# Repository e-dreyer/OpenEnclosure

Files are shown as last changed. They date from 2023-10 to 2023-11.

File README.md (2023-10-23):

# OpenEnclosure

## Important links and the structure of this guide

- For the initial setup, construction and only configuring the `WiFi` of the printer and enclosure, please follow this [guide](https://github.com/e-dreyer/OpenEnclosure/tree/main/intial_setup)
- For the original manual of the CR6-SE, please refer to this [PDF](https://github.com/e-dreyer/OpenEnclosure/tree/main/manual)
- For all of the slicer configs and profiles please refer to the [Slicer Profiles](https://github.com/e-dreyer/OpenEnclosure/tree/main/slicer_profiles) section.

## System Architecture

This is my implementation for my 3D printing enclosure. The enclosure runs the following software:

- **Klipper**: The `firmware` for the printer. [Klipper](https://www.klipper3d.org/) is installed on both the printer and the `Raspberry Pi`
- **Mainsail**: The front-end for `Klipper`, which allows for a simple interface with the printer. You can find the official documentation [here](https://docs.mainsail.xyz/)
- **Moonraker**: An API server used by both `Klipper` and `Mainsail` to communicate with each other. You can find the official documentation [here](https://moonraker.readthedocs.io/)
- **ESP Home**: The `firmware` for the `ESP32` which controls the enclosure heating and lights. You can find the official documentation [here](https://esphome.io/)
- **Mosquito**: A `MQTT Broker` used to implement communication between the `ESP32`, printer and `Raspberry Pi`. Here you can find [easy installation instructions](https://randomnerdtutorials.com/how-to-install-mosquitto-broker-on-raspberry-pi/) but it will be explained in the following sections.

## Fresh Install

This section is only relevant if the user wishes to do a complete fresh installation of the entire system. If you wish to only configure the `WiFi` settings, please refer to this [guide](https://github.com/e-dreyer/OpenEnclosure/tree/main/intial_setup).

This could be necessary if they user bricked the system in some way, which is not easily possible, they wish to reproduce the original system or wish to replicate it and create a new system. It is advised that a user reads the entire installation process for better understanding. This process might appear intimidating, but is actually quite simple and can easily be completed in about an hour of simply typing `Linux` terminal commands.

An important thing to note is, when completing a fresh install, the `Raspberry Pi` will have no network connection initially. Thus, it is required to connect the `Raspberry Pi` to an external monitor with a keyboard and a `wireless dongle`. The fresh operating system `MainsailOS` will then be installed and the initial setup will be completed. Once the network configuration has been completed, the user can disconnect the `Raspberry Pi` from the external monitor and use `SSH` for further configuration.

Only completed the following section if you are running a fresh install. Otherwise skip directly to the network configuration if you wish to connect the system to a new network and the software has already been installed.

### Klipper, Mainsail and Moonraker

In this section we will be installing `MainsailOS`. `MainsailOS` is a `Linux` based operating system, which is pre-configured to run `Klipper`, `Mainsail` and `Moonraker`. This simplifies the installation process and the user is only required to flash a new operating system to the `Raspberry Pi` for the installation of `Klipper`.

We will start by downloading and installing `rpi-imager` on a secondary computer to create an operating system image for the `Raspberry Pi` `SD card`. You can easily download it from [here](https://www.raspberrypi.com/software/) or use the following command on a `Linux` system

```bash
sudo apt install rpi-imager
```

1. Open `rpi-imager` and click `Other specific-purpose OS > 3D Printing > Mainsail OS` and choose the `32-bit` version.
2. Insert the `SD card` of the `Raspberry Pi` into the computer and select it as the storage device for `rpi-imager`.
3. Click the `gear-icon` in the bottom right corner of `rpi-imager`
4. Set `hostname` as `mainsail.local`.
5. Enable `SSH` with `Use password authentication`, default `username = pi` and `password = root`
6. Skip `Configure Wireless LAN` as this does not always work and will be configured in the next step in order to be more reliable and work correctly
7. Click `Save`
8. Click `Write`. If prompted to format the `SD card` click `yes`.
9. Wait for the installation to complete. This might take a few minutes depending on internet speed and the write speed of the `SD card`

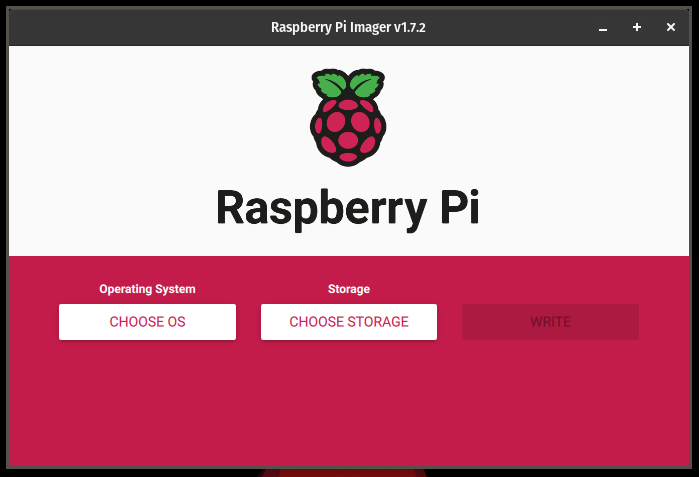
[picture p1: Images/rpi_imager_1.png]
Home screen of RPI imager


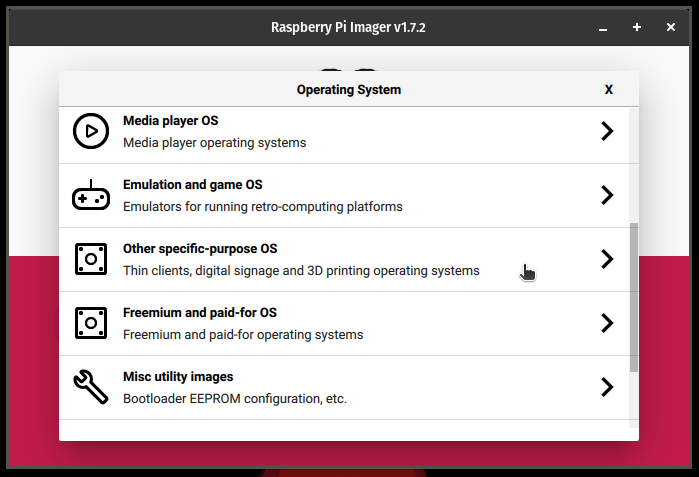
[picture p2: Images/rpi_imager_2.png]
Selecting the image category


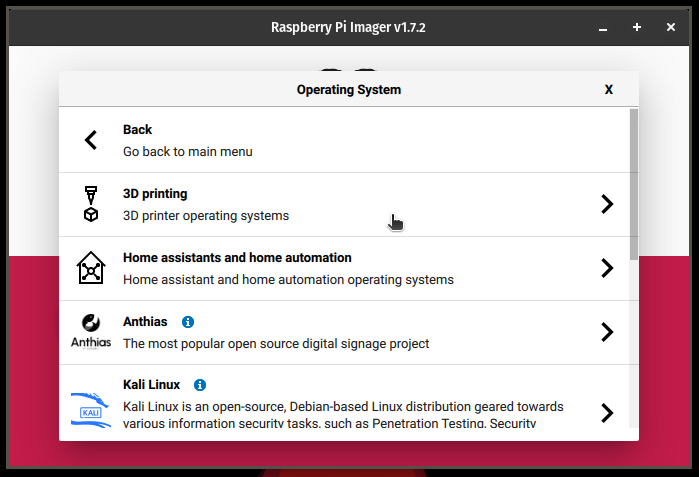
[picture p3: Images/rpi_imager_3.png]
Selecting 3D printing menu


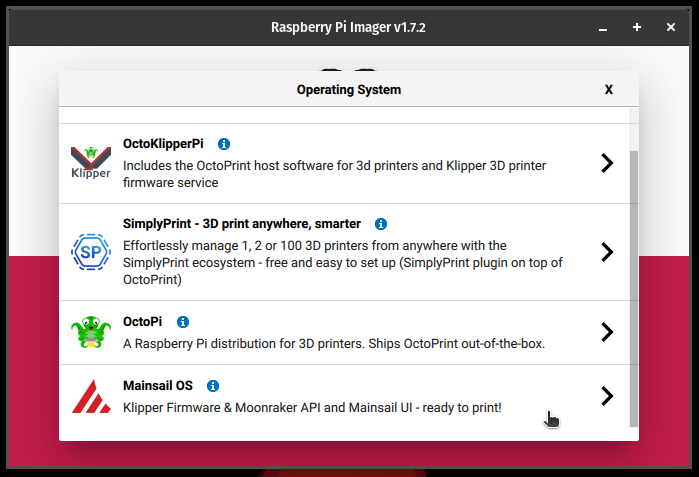
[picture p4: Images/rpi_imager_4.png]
Selecting MainsailOS


Remove the `SD card` from the computer and insert it into the `Raspberry Pi`. Connect the `Raspberry Pi` to an HDMI monitor and a keyboard and finally connect the power. Wait for the `Raspberry Pi` to boot. Ensure that your `WiFi dongle` is plugged into the `Raspberry Pi`.

### Setting up WiFi, SSH and static IP

==This should be completed for the initial setup in order to connect the Raspberry Pi to your network as well as after an initial fresh install of Klipper and MainsailOS as explained in the previous section==

#### Rasp-Config

On the first boot, the screen may flash a test image, simulating a rainbow pattern and present a scrolling terminal of text showing checks and other information. Wait for the this screen to stop scrolling and wait for a prompt asking for your username:

```bash
raspberrypi login: 
```

Enter `pi`. A next prompt asking for your password will be shown. Important, while typing in your password, no text will be shown in the terminal. Enter `root`:

```bash
Password: 
```

Next we need to configure the `Raspberry Pi`. Run the following command in the terminal. You may be prompted for your password, enter the password as configured previously or the default password `root`

```bash
sudo raspi-config
```

Use the arrow keys to select `1 System Options`, select `S1 Wireless LAN` enter the `SSID` of your `WiFi network`. The `SSID` is the name of your network, such as the name shown on a phone or computer when connecting to the network. Be sure to enter it perfectly as it is case-sensitive.

After entering your `SSID` press `enter` and you will be prompted for your `password`. This is the password for your `WiFi network`. Press enter once complete.

You'll be returned to the home screen. Select `1 System Options` again and select `Hostname`. Enter your own desired unique hostname. For this guide the hostname `mainsail` was chosen. Press enter once complete.

On the home screen again, select `3 Interface Options` and select `I2 SSH`, follow the guide to enable `SSH`. Repeat this for the same menu `3 Interface Options` to enable `I4 SPI`, `I5 I2C`, `I6 Serial Port`, `I7 1-Wire` and `I8 Remote GPIO`. 

- `SSH` allows you to login to your `Raspberry Pi` over a remote terminal connection
- `SPI`, `I2C` and `1-Wire` are all communication protocols which can be used to communicate with external sensors and modules. Not all of them are necessarily used with the current implementation, but enabling them might allow for easier setup in the future.
- `Serial Port` allows for serial communication over USB
- `Remote GPIO` allows for controlling the `GPIO` pins remotely. This is often used by some `Android` apps and other applications and enabling it now would also simplify future configurations.

Back on the home screen of `raspi-config`, press the `right-arrow key` to move the cursor to the `Finish` button in the bottom right corner. Press `enter`. If prompted to `reboot`, select `yes` and press `enter`. The `Raspberry Pi` will restart. Wait for this to finish and login with your `username` and `password` again once the reboot has been completed.

#### WiFi

Although the `WiFi` settings have been enabled and you provided your `SSID` and `password` in the previous section, this does not always work, depending on your `Wifi dongle` and network. Thus the following configuration should be completed:

Enter the following commands line by line separately in the terminal, pressing `enter` after every line. Be sure to replace `ssid` with your `WiFi network name` and `password` with your `password`. They should be enclosed by the single quotes.

```bash
sudo rfkill unblock wifi
sudo sh -c "wpa_passphrase 'ssid' 'password' >> /etc/wpa_supplicant/wpa_supplicant.conf"
sudo wpa_cli -i wlan0 reconfigure
```

`Reboot` the `Raspberry Pi` again by typing `reboot` into the terminal. Wait for the `Raspberry Pi` to reboot and login again.

Once the system is booted, enter the command `ifconfig` and you'll be presented by an output such as the following:

```bash
pi@mainsail:~ $ ifconfig
eth0: flags=4099<UP,BROADCAST,MULTICAST>  mtu 1500
        ether b8:27:eb:3c:98:b5  txqueuelen 1000  (Ethernet)
        RX packets 0  bytes 0 (0.0 B)
        RX errors 0  dropped 0  overruns 0  frame 0
        TX packets 0  bytes 0 (0.0 B)
        TX errors 0  dropped 0 overruns 0  carrier 0  collisions 0

lo: flags=73<UP,LOOPBACK,RUNNING>  mtu 65536
        inet 127.0.0.1  netmask 255.0.0.0
        inet6 ::1  prefixlen 128  scopeid 0x10<host>
        loop  txqueuelen 1000  (Local Loopback)
        RX packets 12  bytes 1698 (1.6 KiB)
        RX errors 0  dropped 0  overruns 0  frame 0
        TX packets 12  bytes 1698 (1.6 KiB)
        TX errors 0  dropped 0 overruns 0  carrier 0  collisions 0

wlan0: flags=4163<UP,BROADCAST,RUNNING,MULTICAST>  mtu 1500
        inet 192.168.1.59  netmask 255.255.255.0  broadcast 192.168.1.255
        inet6 fe80::b087:ae52:2982:2133  prefixlen 64  scopeid 0x20<link>
        ether c8:3a:35:c3:d9:3e  txqueuelen 1000  (Ethernet)
        RX packets 655  bytes 145261 (141.8 KiB)
        RX errors 0  dropped 0  overruns 0  frame 0
        TX packets 344  bytes 156595 (152.9 KiB)
        TX errors 0  dropped 0 overruns 0  carrier 0  collisions 0
```

Note the output for `wlan0`, this is the `Wireless dongle`. The section `inet 192.168.1.59` is the `ip address` of the `Raspberry Pi` on your network. `ether c8:3a:35:c3:d9:3e` is the `MAC` address of the dongle. The `ip address` in your output may differ as this is provided by your network and router. The `MAC` address might be the same depending on the dongle you used. 

#### Static IP settings

The `ip address` displayed in the previous section is very important. This is the address of the printer on the network. Although the `ip address` is supplied by your router, it might not remain constant and may change every 48 hours or so, which is not desired. For this reason, we want to supply it with a `static ip address`, this will ensure that the `Raspberry Pi` will always have the same address, which is required for you to easily connect to your printer as well as connect the `ESP32` which controls the enclosure to your printer.

First, we need to find the `ip address` of your `router`. Run the following command to get this:

```bash
ip r | grep default
```

The output should look something like this:

```bash
default via 192.168.1.1 dev wlan0 proto dhcp src 192.168.1.59 metric 303 
```

Note the part `192.168.1.1`, which might differ for you, this is the `ip address` of your router. We will call it `<router ip>` for now, that you can use it in the following sections.

Next, we need to find your `DNS` server. You can find this using the following command. This command will prompt you for your `password` of your `Raspberry Pi` and open the terminal text editor afterwards.

```bash
sudo nano /etc/resolv.conf
```

The output should look something like this:

```bash
# Generated by resolvconf
domain RT-AC58U_V3-3C28
nameserver 192.168.1.1
```

Note the `ip address` after `nameserver`. We will call this `<dns ip>`. Press `ctrl+x` to exit this editor and return to the terminal.

Now we are ready to set the `static ip address`. Start by entering the following command. This will once again open a terminal text-editor.

```bash
sudo nano /etc/dhcpcd.conf
```

The output in your terminal will then possibly be an empty text file or the might be some other configurations. If settings already exist, update the information, other simply enter the following:

- `NETWORK` should be replaced with your interface that you are using, in the case of a `WiFi dongle` you need to enter `wlan0`
- `STATIC_IP/24` should be replaced with your desired `ip address`. For this guide we will use `192.168.1.59/24`. If you choose your own `ip address`, be sure that the third digit marked by an x `192.168.x.y` needs to be the same as the third digit in your `<router ip>` we found earlier and y should always be less than `255` and never numbers like `0`, `1`, `10`, `99` or `100` as they are often used by your network or router, but your could use them if you know what you are doing.
- `ROUTER_IP` should be replaced by your `<router ip>` we found in the previous section.
- `DNS_IP` should be replaced by your `<dns ip>` found in the previous section

```bash
interface NETWORK 
static ip_address=STATIC_IP/24
static routers=ROUTER_IP 
static domain_name_servers=DNS_IP
```

Thus, my implementation looked something like this. Important, if your file contains a lot of other information, do not change any of these settings. Also, if the lines already exist in the file, but they start with a `#`, remove it. The `#` acts as a comment line and these lines are thus commented out and not active, as seen below in my configuration.

```bash
interface wlan0
static ip_address=192.168.1.59/24
static routers=192.168.1.1
static domain_name_servers=192.168.1.1 8.8.8.8 fd51:42f8:caae:d92e::1
```

Once done, press `ctrl+x` and you will be prompted at the bottom of the screen to save the file. Press `shift+y` to select `yes` and press `enter` to confirm to overwrite the file contents. You will then be returned to the terminal screen. Finally, we can `reboot` the system again, by running the command `reboot` in the terminal.

#### Well done first step complete

You have now completed the initial setup of the `Raspberry Pi`. We installed `MainsailOS` which includes `Klipper` and `Mainsail` which we will use to control the printer. We also connected the `Raspberry Pi` to the network and configured a `static ip address` which will ensure that we can easily connect to it over the network. Next we need to install `Klipper` on the printer itself.

## What is Klipper?

Klipper is an open-source firmware which off-sets the computation from the printer to a `Raspberry Pi`. This allows the `Raspberry Pi` to handle all of the heavy computation and only communicates the required kinematics with the printer. This allows for faster printing as well as other advanced features such as [input shaping](https://www.klipper3d.org/Resonance_Compensation.html), [pressure advance](https://www.klipper3d.org/Pressure_Advance.html) and the connection of other external processors and modules.

This process involves two installation. The installation of `Klipper` on the `Raspberry Pi` and on the printer itself. The installation on the `Raspberry Pi` has already been completed in the previous sections and only the printer is remaining.

### Installing Klipper on the printer

Please refer to the [official documentation](https://www.klipper3d.org/Installation.html) but the following guide can also be followed. Also, this step can be skipped and the default `firmware.bin` file can be found in the `firmware/` folder of this repository, copy this file to your `SD card` and skip to the end of this section to flash the file to your printer.

First start by setting up the `Raspberry Pi`. You can connect the `Raspberry Pi` to an HDMI monitor and use a keyboard as in the previous sections or you can connect to the `Raspberry Pi` using `SSH`. This can be achieved using a dedicated `SSH` terminal or using the following command in either `Windows`, `Linux` or `Mac` terminals. Where `pi` is replaced with the username you previously chose and `192.168.1.59` with the `static ip` you chose in the previous steps. Press `enter` and follow the on screen instructions. The terminal will then connect to the `Raspberry Pi` and grant you access to the terminal similar to the terminal you used when the `Raspberry Pi` was directly connected to your monitor. If you aren't using an `SSH` connection, skip the following command and continue directly to the next command where we move to the directory of `Klipper` in the terminal of the `Raspberry Pi`:

```bash
ssh pi@192.168.1.59
```

Once connected to the terminal, enter the following command to move to the directory of `Klipper` on the `Raspberry Pi`:

```bash
cd klipper/
```

Once in this directory, we want to create the `firmware` file you'll be flashing to the printer. First start by entering the following command:

`make menuconfig`

You will then be presented with a menu similar to the the menu you used when we usec `raspi-config` in the previous steps. Use the `arrow keys` to move down to the second option `Micro-controller Architecture (...)` where `...` might be some arbitrary text depending on the last setup used, and press `enter`.

Once again use the `arrow keys` to move down and select `STMicroelectornics STM32` and press `enter`. Select `processor model "STM32F103" (is the default)`, set `Bootloader offset` to `Bootloader - "28KiB"` and `Communication interface` to `Serial (on USART1 PA10/PA9)`. If you get stuck, a great guide can be found [here](https://github.com/KoenVanduffel/CR-6_Klipper). Otherwise, there is also this guide on [Reddit](https://www.reddit.com/r/CR6/comments/jdil9t/klipper_for_the_cr6/).

Menuconfig for the CR6SE

Press `shift+q` and press `shift+y` to save the settings. This will save the config which we want to use for building our firmware. Once back in the terminal, enter the following command to build the firmware for your printer. This might take a few minutes and the terminal may scroll automatically with a lot of logs and information regarding the build:

```bash
make
```

If this is successful, you'll se the file `klipper.bin` in the directory if you enter `ls out/` to list the files in the `out/` directory. This is the file we are interested in. If you have changed anything in the afore mentioned config, you need to copy this file to an `SD Card`, otherwise this file has already be provided in the `firmware` folder of this repository and you can simply copy it to an `SD card` and rename it to `firmware.bin`. Please note, that this `klipper.bin` file was generated on 2023-10-19 and might be out of date at the time of your usage.

Copy this `firmware.bin` file to your `SD card`. Be sure to turn your printer off. Insert the `SD card` and `power-on` the printer. Wait for the about `60 seconds` for the printer to automatically install the firmware. Be sure that the printer is `off` before inserting the `SD card` and is turned on while it is already inserted. The printer checks for this file on the `SD card` at startup.

Important. For some reason, this step isn't always successful. In my personal experience it always takes about 2 or 3 tries. So I insert the `SD card`, power-on the printer, wait `60 seconds` and then power the printer off. I then repeat this process 2 or 3 times to be sure that it flashes. This is simply due the printer's nature and is a well known "bug" with this process. If you find that the `Raspberry Pi` cannot connect to the printer in the following sections or that it does not detect it, it might be due to this step failing.

If you are unable to flash the firmware, please confirm that the correct settings were chosen in the previous section.

### Installing Klipper MCU for the Raspberry Pi

Due to certain dependencies, their is a third and final `Klipper` installation which needs to be completed for this implementation to work correctly. This involves installing some low-level firmware of `Klipper` to allow the `Linux` operating system on the `Raspberry Pi` to communicate with some of the hardware on the `Raspberry Pi`. This is however quite easy and can be completed with the following commands, the official documentation for this process can also be found [here](https://www.klipper3d.org/RPi_microcontroller.html).

```bash
cd ~/klipper/
sudo cp ./scripts/klipper-mcu.service /etc/systemd/system/
sudo systemctl enable klipper-mcu.service
```

Then we need to compile the `firmware` for the for the `Raspberry Pi`, similar to the `firmware` we compiled for the printer:

```bash
cd ~/klipper/
make menuconfig
```

In the menu, set `Microcontroller Architecture` to `Linux process` then save and exit. Finally, we can flash it to the `Raspberry Pi`:

Menuconfig for the Linux Process

```bash
sudo service klipper stop
make flash
sudo service klipper start
```

### Configuring Klipper

`Klipper` functions a bit differently to the standard `Marlin` firmware shipped with most printers. Rather than having the configuration of the printer be fixed at compile time of the `firmware`, you can change it at anytime. Thus, you can change certain features on your printer after flashing the `firmware.bin` file to your printer. These settings are contained in the `printer.cfg` file. Please refer to the following page on the `Klipper` website for more information regarding [the configuration file](https://www.klipper3d.org/Config_Reference.html). You can also find the official Creality config file on their Github, which they used for their SonicPad which can be found [here](https://github.com/CrealityOfficial/Creality_Sonic_Pad/tree/main/printer_configrations).

It is not required to understand everything, but the configuration defines all the parameters, limits and specifications of the printer for Klipper to operate. A perfect starting `printer.cfg` file for this implementation can be found on the `configurations/` directory of this repository. We'll start by copying all of the content in the `configurations/` folder in this repository to the `printer_data` folder on the `Raspberry Pi`. This will copy the `config` folder which contains all of the configurations, as well as some example g-code in the `gcode` folder and finally some other files such as the `moonraker.secrets` file which contains credentials used by `Moonraker` to connect to the MQTT server we will install in the following sections.

First start by ensuring that you are in the `root` directory of the `Raspberry Pi`, by running the following command

```bash
cd ~
```

Then we want to `clone` this `repository` to the `Raspberry Pi`. What this does exactly isn't really important, but you can imagine it to downloading and copy all of the files in this `repository` to the `Raspberry Pi`, which make a lot of tasks easier.

While still in the `root` directory, run the following command to `clone` this repository. There might be some text output to the terminal during this process:

```bash
git clone https://github.com/e-dreyer/OpenEnclosure.git
```

The output should look something like this:

```bash
pi@mainsail:~ $ git clone https://github.com/e-dreyer/OpenEnclosure.git
Cloning into 'OpenEnclosure'...
remote: Enumerating objects: 89, done.
remote: Counting objects: 100% (89/89), done.
remote: Compressing objects: 100% (64/64), done.
remote: Total 89 (delta 37), reused 72 (delta 24), pack-reused 0
Receiving objects: 100% (89/89), 177.15 KiB | 643.00 KiB/s, done.
Resolving deltas: 100% (37/37), done.
```

We can then move into this directory with the following command

```bash
cd OpenEnclosure
```

Using the following command, you will be able to see all of the files in this repository now on your `Raspberry Pi`:

```bash
ls
```

Now let's copy some of these files over to the correct `Klipper` directories to configure your `Klipper` installation. Let's first navigate back to the `root` directory to make things easier:

```bash
cd ~
```

Now we want to copy all of the config files to the correct `Klipper` directory. This command copies all of the files in `OpenEnclosure/configurations/config` to `printer_data/config` on the `Raspberry Pi` and the `-r` flag specifies this operation to be recursive to ensure that all sub folders and files are also copied over:

```bash
cp -r OpenEnclosure/configurations/config/* printer_data/config/
```

Finally, we just need to copy over some files which are used to store `passwords` and other configurations:

```bash
cp OpenEnclosure/configurations/moonraker.asvc printer_data/
```

```bash
cp OpenEnclosure/configurations/moonraker.secrets printer_data/
```

We are almost done, we only have two more systems to install, then we can start printing!

## MQTT Broker

Next we need to install an `MQTT Broker` on the `Raspberry Pi`. `MQTT` is a communication protocol often used by `Internet-of-things` or `IOT` devices and is similar to the `http://...` or `https://...` you see before website `urls`, but specifically made for devices such as printers and the enclosure. A `MQTT Broker` can be seen as a server and allows other devices to talk to each other over this server. In this case, a `MQTT Broker` will be hosted on the `Raspberry Pi` and the `ESP32` of the enclosure and the `Moonraker API` we installed along side `Klipper` in the first section will talk to each other. This setup is far easier than it sounds and also involves only a few terminal commands.

[Here](https://randomnerdtutorials.com/how-to-install-mosquitto-broker-on-raspberry-pi/) you can find an easy tutorial to install the `Mosquitto MQTT Broker`, but it will also be explained below. First we need to update the `Raspberry Pi`. This will allow it to have the latest versions of the software. You can do this by running the following command. While this command is running, you might be prompted to confirm certain software installations by pressing `shift+Y` to confirm `yes`. Also, initially you will be prompted for you password as the `sudo` keyword is used. This is the `password` of the `Raspberry Pi`, in this guide we previously defined it as `root`

```bash
sudo apt update && sudo apt upgrade
```

Now we are ready to install `Mosquitto`, let's start by first running the following command:

```bash
sudo apt install -y mosquitto mosquitto-clients
```

We also want `Mosquitto` to auto-start when the `Raspberry Pi` is powered on. You can enable this by entering the following command:

```bash
sudo systemctl enable mosquitto.service
```

We can now test our `MQTT Broker` by entering the following command. The `-v` flag is for the `verbose` mode, which enables `logging`. The `MQTT Broker` should start and you should see a log of text and information scrolling on the terminal:

```bash
mosquitto -v
```

This is great, but we need to enable some security to only allow a device to connect to the `MQTT Broker` with a specific `username` and `password`. An important thing to note here is that the `MQTT Broker` only has a single `username` and `password`. Thus, it is configured once and all devices connecting to it should use this specific `username` and `password`. You can chose any `username` and `password`, but I advise using good security practices with strong `passwords` for this:

Let's start by creating a new `username` with the following command, where `YOUR_USERNAME` is the `username` you would like to use

```bash
sudo mosquitto_passwd -c /etc/mosquitto/passwd YOUR_USERNAME
```

For this guide, I will be using `username = mainsail` and my command looked something like this:

```bash
sudo mosquitto_passwd -c /etc/mosquitto/passwd mainsail
```

When you run the preceding command with the desired `username`, you’ll be asked to enter a `password`. No characters will be displayed while you enter the `password`. Enter the `password` and memorize the user/pass combination, you’ll need it later in your projects to make a connection with the `MQTT Broker`. This previous command creates a `password` file called `passwd` on the `/etc/mosquitto` directory.

Run the following command to edit this file:

```bash
sudo nano /etc/mosquitto/mosquitto.conf
```

Add the following line at the `top` of the file (make sure it is at the `top` of the file, otherwise it won’t work):

```bash
per_listener_settings true
```

Add the following three lines to `allow` connection for `authenticated` users and tell `Mosquitto` where the username/password file is located.

```bash
allow_anonymous false
listener 1883
password_file /etc/mosquitto/passwd
```

Your configuration file will look as follows

```bash
# Place your local configuration in /etc/mosquitto/conf.d/
#
# A full description of the configuration file is at
# /usr/share/doc/mosquitto/examples/mosquitto.conf.example

per_listener_settings true

pid_file /run/mosquitto/mosquitto.pid

persistence true
persistence_location /var/lib/mosquitto/

log_dest file /var/log/mosquitto/mosquitto.log

include_dir /etc/mosquitto/conf.d
allow_anonymous false 
listener 1883  
password_file /etc/mosquitto/passwd
```

Press `ctrl+x`, then `shift+y`, and finally press `enter` to exit and save the changes.

Restart `Mosquitto` for the changes to take effect.

```bash
sudo systemctl restart mosquitto
```

To check if `Mosquitto` is actually running, you can run the following command:

```bash
sudo systemctl status mosquitto
```

You can press `ctrl+d` or `ctrl+c` to exit this output.

It is now a good time for us to restart the `Raspberry Pi` to save all of these settings. You can do this by running the command:

```bash
reboot
```

Finally, we just need to set this `username` and `password` for `Moonraker`, let's open the `moonraker.secrets` file to do this. If you are not in the `root` directory, start by going to the root directory with `cd ~` and then open the file with:

```bash
nano printer_data/moonraker.secrets
```

You'll be presented with a file, similar to this following output. Change the `username` and `password` to the values you configured for your `MQTT Broker`:

```bash
[mqtt_credentials]
username: mainsail
password: root
```

To save, we press `ctrl+x`, `ctrl+y` and then press `enter` as we did in the previous sections to exit the `nano` text editor.

We are now ready for the last section of this installation and then we can start printing!

## Enclosure and ESP32

In this section we will install and configure the `ESP32` which is used to control the enclosure. The `ESP32` is a small `microcontroller` with `WiFi` capabilities. After this section it will be able to connect to the `Raspberry Pi` over `WiFi` and receive information regarding its operation and the desired temperature settings. To achieve this, we need to install the `ESP Home` firmware on the `ESP32`. This involves a pre-configured `config` file `.yaml` file. The user is however only required to make changes to the `secrets.yaml` file which will set the `static ip` similar to what we did with the `Raspberry Pi` in the previous sections, configure the `credentials` to the `network` and our `MQTT Broker` and finally, one or two other required parameters.

The enclosure is controlled by an ESP32 and has the following features:

- A temperature sensor `enclosure_temperature_sensor` for measuring the temperature of the enclosure.
- A set of heating lamps `enclosure_heating_lights` which are used to heat the enclosure.
- A configured climate and PID `enclosure_heating_lights_climate` to control the brightness of `enclosure_heating_lights` to establish a stable and controlled temperature. The temperature is measured by `enclosure_temperature_sensor`
- The dimming of the `enclosure_heating_lights` are controlled by `enclosure_heating_lights_climate` and is implemented using a Triac AC Dimmer `enclosure_heating_lights_dimmer`

### Installing ESP Home on the Raspberry Pi

First we need to install `ESP Home` on the `Raspberry Pi`, which would allow us to flash the `firmware` for the `ESP32`. Let's start by first moving to the `root` directory on the `Raspberry Pi`:

```bash
cd ~
```

And then we want to move to the `OpenEnclosure` folder we cloned in the previous sections. If you have not done this before, first `clone` this repository:

```bash
git clone https://github.com/e-dreyer/OpenEnclosure.git
```

Otherwise, simply move to the `OpenEnclosure` directory from the `root` directory with:

```bash
cd OpenEnclosure
```

First we want to make sure `Python` is installed, you can easily verify this with:

```bash
python --version
```

You should see something like this, as it would have been installed alongside `Klipper` and `MainsailOS`

```bash
pi@mainsail:~ $ python --version
Python 3.9.2
```

Then we are ready to install `ESP Home`, you can do this by running the following two commands. Please note, after entering these commands separately and pressing `enter`, the terminal might not immediately output anything and it might appear as if nothing is happening. Please wait about `30 seconds` as output will soon start to appear.

This process can also be found in the official documentation of `ESP Home` [here](https://esphome.io/guides/installing_esphome).

First ensure that `Python virtual environments` are installed by running:

```bash
sudo apt-get install python3-venv
```

Then we create the virtual environment

```bash
python3 -m venv venv
```

And we activate the virtual environment with:

```bash
source venv/bin/activate
```

Please not that after activating the `virtual environment` your terminal will change and look like this:

```bash
(venv) pi@mainsail:~/OpenEnclosure $ 
```

The reason for this is we are using `Python virtual environments` which allows for isolated control over dependencies. Finally, we install `ESP Home` with:

```bash
pip3 install esphome
```

You can verify that this was successful with the following command:

```bash
esphome version
```

You should see something like this:

```bash
(venv) pi@mainsail:~/OpenEnclosure $ esphome version
Version: 2023.10.1
```

Awesome! Let's install the `firmware` to the `ESP32`. Let's start by moving to the correct directory with:

```bash
cd enclosure
```

In this folder we have a few files, the two important ones are `enclosure.yaml` and `secrets.yaml`. The `enclosure.yaml` file contains the entire configuration for the `firmware`. This file allows us to program the `firmware` with a simple configuration file. If you look at this file, you will see that it defines different `pins` and `behaviors` for the `ESP32`. Finally, we have the `secrets.yaml` file, which contains our credentials and other parameters. Let's open this file to edit it:

```bash
nano secrets.yaml
```

You should see something like this:

```bash
wifi_ssid: YOUR_WIFI_SSID
wifi_password: YOUR_WIFI_PASSWORD
wifi_ip: 192.168.1.74 # Your static IP for your ESP32
wifi_gateway: 192.168.1.1 # Your default gateway, this is the <router ip> we got in a previous section
wifi_subnet: 255.255.255.0 # Your subnet mask, this is almost always 255.255.255.0

ap_ssid: enclosure 
ap_password: password 

ota_password: password 

mqtt_broker: 192.168.1.59 # This is the IP of your Raspberry Pi
mqtt_username: mainsail # This is your MQTT username
mqtt_password: root # This is your MQTT password
```

Here you need to change a few things:

- You need to change `YOUR_WIFI_SSID` to the name of your `WiFi` network, similar to how we connected the `Raspberry Pi` to your `WiFi`.
- You also need to change and set the `YOUR_WIFI_PASSWORD` to the `password` of your `WiFi` network.
- `wifi_ip` will be the `ip address` that you want for the `ESP32`, similar to how we set the `static ip` of the `Raspberry Pi`, you need to chose an `ip address` for the `ESP32`.
- `wifi_gateway` will be the same as the `<router ip>` we found in the previous section
- `wifi_subnet` is the `subnet mask` of your router. For most users this will always be `255.255.255.0`.

- `ap_ssid` is the name for a `hotspot` the `ESP32` can create. If the `ESP32` is unable to connect to a `WiFi` network, it will create its own `access point` and you will be able to connect to it and set the `ssid` and `password` in your browser.
- `ap_password` will be the `password` of this `hotspot` which the `ESP32` creates.

- `ota_password` is the password which `esp_home` on the `Raspberry Pi` can use to update the `ESP32` over the network, thus eliminating the need for a `USB` cable in the future.

- `mqtt_broker` needs to be the `ip address` of the `Raspberry Pi`. You can find this by using the `ifconfig` command in the terminal of the `Raspberry Pi`, similar to how we did it in previous sections of the guide.
- `mqtt_username` is the username you used for your `MQTT Broker` from the previous section.
- Finally, `mqtt_password` is the `password` for your `MQTT Broker` from the previous section.

Now we are ready to flash the `firmware` to the `ESP32`. First start by opening the bottom panel on the side of the enclosure. The panel should look like this.

Closed enclosure side panel

Open the enclosure by pulling of the top panel, it should look something like this:

Opened enclosure side panel

Ensure that the enclosure is not powered on, this can be notices by the LCD display and lights not be powered on. You can achieve this by disconnecting the main AC plug of the enclosure

Powered off enclosure side panel

Note the orientation of the `ESP32` in the enclosure. Carefully disconnect it by pulling it out of the enclosure. Be sure to hold on to the back panel which the `ESP32` is mounted on, as it can also be removed to reveal the wiring of the `ESP32`:

ESP32 mounting orientation

Connect the `ESP32` with a `USB` cable to the `Raspberry Pi`. Preferably not the `USB` cable used to connect the printer, as it does not provide power to the `ESP32` and the red `LED` on the `ESP32` will not turn on when plugged in:

ESP32 connected to printer

Power on the enclosure, by connecting the AC plug again and wait for the `Raspberry Pi` to boot. After a few minutes you can `SSH` into the `Raspberry Pi` again, or use an externally connected monitor, this is your choice.

Once back in the terminal of the `Raspberry Pi`, let's go back to the directory of the `ESP Home` config, with the following commands

```bash
cd ~
cd OpenEnclosure
```

Now we first need to activate the `Python virtual environment` again with the following command:

```bash
source venv/bin/activate
```

Please not that after activating the `virtual environment` your terminal will change and look like this:

```bash
(venv) pi@mainsail:~/OpenEnclosure $ 
```

Now we can move to the directory of the `.yaml` config file:

```bash
cd enclosure
```

Now we can upload the `firmware` to the `ESP32` with the following command:

```bash
esphome run enclosure.yaml
```

This will run for a while as it is possible that you might not have all the required dependencies the first time you run this command. This can easily take about `10` to `15` minutes the first time you run it.

After this command has run for a while, you will be presented with the following prompt:

```bash
INFO Successfully compiled program.
Found multiple options for uploading, please choose one:
  [1] /dev/ttyUSB0 (CP2102 USB to UART Bridge Controller - CP2102 USB to UART Bridge Controller)
  [2] Over The Air (192.168.1.74)
(number): 
```

This gives us 1 of 2 options. The first option is to flash the `firmware` over the `USB` cable, while second option is for `OTA` or `Over-the-air updates` which allows us to update the `ESP32` over `WiFi`. As the `ESP32` is not yet connected to the `WiFi` network, we will press `1` and then `enter`.

The output should look something like this:

```bash
INFO Successfully compiled program.
Found multiple options for uploading, please choose one:
  [1] /dev/ttyUSB0 (CP2102 USB to UART Bridge Controller - CP2102 USB to UART Bridge Controller)
  [2] Over The Air (192.168.1.74)
(number): 1
esptool.py v4.6.2
Serial port /dev/ttyUSB0
Connecting....
Chip is ESP32-D0WD (revision v1.0)
Features: WiFi, BT, Dual Core, 240MHz, VRef calibration in efuse, Coding Scheme None
Crystal is 40MHz
MAC: 8c:aa:b5:a2:a0:04
Uploading stub...
Running stub...
Stub running...
Changing baud rate to 460800
Changed.
Configuring flash size...
Auto-detected Flash size: 4MB
Flash will be erased from 0x00010000 to 0x0011dfff...
Flash will be erased from 0x00001000 to 0x00005fff...
Flash will be erased from 0x00008000 to 0x00008fff...
Flash will be erased from 0x0000e000 to 0x0000ffff...
Compressed 1103120 bytes to 718365...
Wrote 1103120 bytes (718365 compressed) at 0x00010000 in 17.3 seconds (effective 510.6 kbit/s)...
Hash of data verified.
Compressed 17440 bytes to 12128...
Wrote 17440 bytes (12128 compressed) at 0x00001000 in 0.6 seconds (effective 235.6 kbit/s)...
Hash of data verified.
Compressed 3072 bytes to 144...
Wrote 3072 bytes (144 compressed) at 0x00008000 in 0.1 seconds (effective 330.8 kbit/s)...
Hash of data verified.
Compressed 8192 bytes to 47...
Wrote 8192 bytes (47 compressed) at 0x0000e000 in 0.1 seconds (effective 463.2 kbit/s)...
Hash of data verified.

Leaving...
Hard resetting via RTS pin...
INFO Successfully uploaded program.
INFO Starting log output from /dev/ttyUSB0 with baud rate 115200
```

After this process has been completed, you will start to see `logging` and other information from the `ESP32`, which verifies that flashing the `firmware` was successful and it has successfully connected to the `MQTT Broker` on the `Raspberry Pi`. You might however notice some errors, this will be due to the `ESP32` not being connected to the sensors in the enclosure, so you can ignore them for now:

```bash
INFO Successfully uploaded program.
INFO Starting log output from /dev/ttyUSB0 with baud rate 115200
[11:17:03][I][logger:271]: Log initialized
[11:17:03][C][ota:473]: There have been 0 suspected unsuccessful boot attempts.
[11:17:03][D][esp32.preferences:114]: Saving 1 preferences to flash...
[11:17:03][D][esp32.preferences:143]: Saving 1 preferences to flash: 0 cached, 1 written, 0 failed
[11:17:03][I][app:029]: Running through setup()...
[11:17:03][I][i2c.arduino:183]: Performing I2C bus recovery
[11:17:03][C][switch.gpio:011]: Setting up GPIO Switch 'Printer Power'...
[11:17:03][D][switch:016]: 'Printer Power' Turning OFF.
[11:17:03][D][switch:055]: 'Printer Power': Sending state OFF
[11:17:03][D][switch:016]: 'Printer Power' Turning OFF.
[11:17:03][C][switch.gpio:011]: Setting up GPIO Switch 'LED Lights Power'...
[11:17:03][D][switch:016]: 'LED Lights Power' Turning OFF.
[11:17:03][D][switch:055]: 'LED Lights Power': Sending state OFF
[11:17:03][D][switch:016]: 'LED Lights Power' Turning OFF.
[11:17:03][C][light:035]: Setting up light 'Enclosure Heating Lights'...
[11:17:03][D][light:036]: 'Enclosure Heating Lights' Setting:
[11:17:03][D][light:041]:   Color mode: 
[11:17:03][D][light:085]:   Transition length: 1.0s
[11:17:03][D][main:409]: Booting
[11:17:03][D][light:036]: 'Enclosure Heating Lights' Setting:
[11:17:03][D][light:085]:   Transition length: 1.0s
[11:17:03][D][climate:011]: 'Enclosure Heating Lights Climate' - Setting
[11:17:03][D][climate:015]:   Mode: HEAT
[11:17:03][D][climate:040]:   Target Temperature: 0.00
[11:17:03][D][climate:378]: 'Enclosure Heating Lights Climate' - Sending state:
[11:17:03][D][climate:381]:   Mode: HEAT
[11:17:03][D][climate:383]:   Action: OFF
[11:17:03][D][climate:401]:   Current Temperature: nan°C
[11:17:03][D][climate:407]:   Target Temperature: 0.00°C
[11:17:03][C][sgp4x:012]: Setting up SGP4x...
[11:17:03][E][sensirion_i2c:085]: Failed to write i2c register=0x3682 (2) err=2,
[11:17:03][E][sgp4x:017]: Failed to read serial number
[11:17:03][E][component:113]: Component sgp4x.sensor was marked as failed.
[11:17:03][C][dht:011]: Setting up DHT...
[11:17:03][D][sensor:094]: 'Enclosure Heating Lights PID Proportional': Sending state 0.00000 % with 1 decimals of accuracy
[11:17:03][D][sensor:094]: 'Enclosure Heating Lights PID Integral': Sending state 0.00000 % with 1 decimals of accuracy
[11:17:03][D][sensor:094]: 'Enclosure Heating Lights PID Derivative': Sending state 0.00000 % with 1 decimals of accuracy
[11:17:03][C][wifi:038]: Setting up WiFi...
[11:17:03][C][wifi:051]: Starting WiFi...
[11:17:03][C][wifi:052]:   Local MAC: 8C:AA:B5:A2:A0:04
[11:17:03][D][wifi:428]: Starting scan...
[11:17:03][W][dht:169]: Requesting data from DHT failed!
[11:17:03][W][dht:060]: Invalid readings! Please check your wiring (pull-up resistor, pin number).
[11:17:03][D][esp32.preferences:114]: Saving 3 preferences to flash...
[11:17:03][D][esp32.preferences:143]: Saving 3 preferences to flash: 3 cached, 0 written, 0 failed
[11:17:03][D][sensor:094]: 'Enclosure Heating Lights PID Error': Sending state 0.00000 % with 1 decimals of accuracy
[11:17:03][D][sensor:094]: 'Enclosure Temperature': Sending state nan °C with 1 decimals of accuracy
[11:17:03][D][sensor:094]: 'Enclosure Heating Lights PID Proportional': Sending state 0.00000 % with 1 decimals of accuracy
[11:17:03][D][sensor:094]: 'Enclosure Heating Lights PID Integral': Sending state 0.00000 % with 1 decimals of accuracy
[11:17:03][D][sensor:094]: 'Enclosure Heating Lights PID Derivative': Sending state 0.00000 % with 1 decimals of accuracy
[11:17:03][D][climate:378]: 'Enclosure Heating Lights Climate' - Sending state:
[11:17:03][D][climate:381]:   Mode: HEAT
[11:17:03][D][climate:383]:   Action: IDLE
[11:17:03][D][climate:401]:   Current Temperature: nan°C
[11:17:03][D][climate:407]:   Target Temperature: 0.00°C
```

Once you received this output. You can power off the `Raspberry Pi` and unplug the `AC` plug of the enclosure and install the `ESP32` back into the enclosure. Please note the orientation is EXTREMELY important and that the pins are correctly alligned. They should fit perfectly as there is the correct amount of pins.

ESP32 mounting orientation

### ESP Home Configuration Explanation

In this section for interest sake the configuration for `ESP Home` will be explained, but is not necessary.

A standard config file is used for the [ESP Home](https://esphome.io/) setup. This configuration requires the implementation of a `secrets.yaml` file which allows sensitive information to be hidden in the config file. The following sections are included in the configuration:

[ESPHome Core config](https://esphome.io/components/esphome)

```yaml
esphome:
  name: <unique name of your node>
  comment: <descriptive comment for front-ends and your own reference>
  friendly_name: <friendly name to be used in front-ends>

  # Automation executed at boot time
  on_boot:
    priority: 600
    then:
      - logger.log: "Booting"
      - light.turn_off: enclosure_heating_lights
      # This section can be commented out to change the OTA password over Wi-Fi after setup
      # - lambda: |-
      #   id(my_ota).set_auth_password("New password");

  # Automation executed when shutting down
  on_shutdown:
    priority: 600
    then:
      - logger.log: "Shuting down"
      - light.turn_off: enclosure_heating_lights
```

#### board specific configuration

The following section specifies the board used by the config and should be changed according to your board:

- [ESP8266](https://esphome.io/components/esp8266)
- [ESP32](https://esphome.io/components/esp32)
- [RP2040](https://esphome.io/components/rp2040)

```yaml
# ESPHome Processor settings
esp32:
  board: esp32doit-devkit-v1
  framework:
    type: arduino
```

#### OTA

[ESPHome OTA](https://esphome.io/components/ota)

Over-the-air or OTA allows for updates over a Wi-Fi connection. The initial installation requires a `serial` connection to a host PC but future updates can be performed over Wi-Fi:

```yaml
ota:
  password: !secret ota_password

  # Automation on start
  on_begin:
    then:
      - logger.log: "OTA start"

  # Automation during upload
  on_progress:
    then:
      - logger.log:
          format: "OTA progress %0.1f%%"
          args: ["x"]

  # Automation on end
  on_end:
    then:
      - logger.log: "OTA end"

  # Automation on error
  on_error:
    then:
      - logger.log:
          format: "OTA update error %d"
          args: ["x"]
```

#### Wi-Fi

[ESPHome Wi-Fi](https://esphome.io/components/wifi)

The following section defines the Wi-Fi configuration for the `ESPHome` node. It also specifies a fall-back access-point which is used when Wi-Fi isn't available or credentials have incorrectly been configured. The user can then connect to the network of the node and configure the network credentials.

This also includes the `ESPHome` captive portal which allows for a useful and attractive UI over Wi-Fi and the access-point.

```yaml
# Wifi settings
wifi:
  # Credentials
  ssid: !secret wifi_ssid
  password: !secret wifi_password

  # IP settings
  manual_ip:
    static_ip: !secret wifi_ip
    gateway: !secret wifi_gateway
    subnet: !secret wifi_subnet

  # Wifi-fallback settings for access point
  ap:
    ssid: !secret ap_ssid
    password: !secret ap_password

# ESPHome Captive Portal settings
captive_portal:
```

#### MQTT

[ESPHome MQTT](https://esphome.io/components/mqtt)

This section defines the setup for the MQTT functionality of the enclosure:

```yaml
# ESPHome MQTT settings
mqtt:
  # First the MQTT credentials are specified
  broker: !secret mqtt_broker # Broker IP
  username: !secret mqtt_username # Broker username
  password: !secret mqtt_password # Broker password

  # A birth message which will be posted on-connect can then be defined
  birth_message:
    topic: enclosure/status
    payload: online

  # As well as a last will message. This allows for detection of the state of the ESPHome Node over MQTT
  will_message:
    topic: enclosure/status
    payload: offline

  # Then initial topics to subscribe to are specified
  on_json_message:

    # In my case I configured it to detect the temperature from a sensor connected to my Raspberry pi
    - topic: cr6semainsail/klipper/state/temperature_sensor enclosure_temperature/temperature # Topic from Moonraker Config
      then:
      # Set the template sensor, this acts as a virtual sensor
      - sensor.template.publish:
          id: enclosure_temperature_sensor

          # Get the value from the JSON format
          state: !lambda |-
            return x["value"];
    
    # It also receives the temperature target as provided by Klipper and Moonraker, which allows for the usage of G-code commands
    - topic: cr6semainsail/klipper/state/temperature_sensor enclosure_temperature/target # Topic from Moonraker Config
      then:
      # Set the PID control
      - climate.control:
          id: enclosure_heating_lights_climate # Climate controller
          mode: HEAT

          target_temperature: !lambda |-
            return x["value"];
```

#### Climate Control

[ESPHome Climate](https://esphome.io/components/climate/)

The enclosure is configured as an `ESPHome` `climate`, which allows for the configuration of a PID. This PID is then fed back to the AC dimmer and lights

```yaml
# ESPHome Climate PID control
climate:
  - platform: pid
    id: enclosure_heating_lights_climate # ID of the PID controller
    name: "Enclosure Heating Lights Climate"
    sensor: enclosure_temperature_sensor # Sensor to use as the input
    default_target_temperature: 21°C

    heat_output: enclosure_heating_lights_dimmer # The ESPHome output

    # Control parameters calculated by autotune
    control_parameters:
      kp: 1.01859 #0.29030
      ki: 0.00328 #0.00087
      kd: 0.0 #79.04271

      output_averaging_samples: 20      # smooth the output over 10 samples
      derivative_averaging_samples: 20  # smooth the derivative value over 10 samples

    # Set deadband to + or - 1.0°C
    deadband_parameters:
      threshold_high: 2.0°C
      threshold_low: -2.0°C

    # These settings are required for correct behavior in HomeAssistant
    visual:
      min_temperature: 0 °C
      max_temperature: 65 °C
      temperature_step: 1 °C
```

#### Sensors

[ESPHome PID](https://esphome.io/components/climate/pid)

With `ESPHome` most outputs can be configured as sensors, which allows for many different use cases. It can also be used to publish the state of the PID:

```yaml
# ESPHome sensors
sensor:

  # This sensor acts as a virtual sensor which is updated over MQTT from Moonraker
  - platform: template
    name: "Enclosure Temperature Sensor"
    id: enclosure_temperature_sensor
    device_class: "temperature"
    state_class: "measurement"
    accuracy_decimals: 2

    filters:
      - heartbeat: 1.0s

  # Show PID parameters on MQTT
  - platform: pid
    name: "Enclosure Heating Lights PID Result"
    id: enclosure_heating_lights_pid_result
    climate_id: enclosure_heating_lights_climate

    type: RESULT
    state_class: "measurement"
    accuracy_decimals: 2

    filters:
      # Help scale the PID output to a value between 0 and 255
      - calibrate_linear:
          - 0.0 -> 0.0
          - 100.0 -> 255.0
      # Send a heartbeat value to smooth PID output
      - heartbeat: 1.0s
      # Sliding window to smooth the temperature
      - sliding_window_moving_average:
          window_size: 20
          send_every: 20
      # Return 0 for negative values
      - lambda: !lambda |-
          if (x < 0) {
            return 0;
          }
          else {
            return x;
          }

#   Used for debugging purposes
  - platform: pid
    name: "Enclosure Heating Lights PID Error"
    id: enclosure_heating_lights_pid_error
    climate_id: enclosure_heating_lights_climate
    type: ERRORNETWORK
    state_class: "measurement"
    accuracy_decimals: 2
    filters:
      - heartbeat: 1.0s

  - platform: pid
    name: "Enclosure Heating Lights PID Proportional"
    id: enclosure_heating_lights_pid_proportional
    climate_id: enclosure_heating_lights_climate
    type: PROPORTIONAL
    state_class: "measurement"
    accuracy_decimals: 2

  - platform: pid
    name: "Enclosure Heating Lights PID Integral"
    id: enclosure_heating_lights_pid_integralNETWORK
    climate_id: enclosure_heating_lights_climate
    type: INTEGRAL
    state_class: "measurement"
    accuracy_decimals: 2
    
  - platform: pid
    name: "Enclosure Heating Lights PID Derivative"
    id: enclosure_heating_lights_pid_derivative
    climate_id: enclosure_heating_lights_climate
    type: DERIVATIVE
    state_class: "measurement"
    accuracy_decimals: 2
```

#### OutputNETWORK

[ESPHome AC Dimmer](https://esphome.io/components/output/ac_dimmer)

The dimmer is used as the output to control the lights

```yaml
# ESPHome Output
output:

  # Triac AC dimmer used to control the heating lights in the enclosure
  - platform: ac_dimmer
    id: enclosure_heating_lights_dimmer

    gate_pin: GPIO12 # This is the PWM Output
    
    zero_cross_pin:
      number: GPIO5 # The is the ZC input
      mode:
        input: true

    method: leading

    min_power: 30%
    max_power: 100%
    zero_means_zero: true # A value of zero turns the PID off
```

#### Lights

[ESPHome Light](https://esphome.io/components/light/)
[ESPHome Monochromatic Light](https://esphome.io/components/light/monochromatic)

The lights are configured to be controlled by the dimmer, which is in turn controlled by the PID

```yaml
# ESPHome Lights
light:
  # This is the heating lights used in the enclosure
  - platform: monochromatic
    name: "Enclosure Heating Lights"
    id: enclosure_heating_lightsNETWORK

    output: enclosure_heating_lights_dimmer # Is controlled by the dimmer
```

#### Button

[ESPHome Button](https://esphome.io/components/button/)

A simple virtual button is set-up to trigger the auto-tune functionality of the PID system. This can be triggered through `Home Assistant` or via a physical button.

```yaml
# ESPHome Button
button:
  # Autotune functionality for the PID in HomeAssistantNETWORK
  - platform: template
    name: "Enclosure Heating Lights PID Autotune"
    id: enclosure_heating_lights_pid_autotune

    on_press:
      - climate.pid.autotune: enclosure_heating_lights_climate
```

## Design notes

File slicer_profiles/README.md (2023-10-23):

# Importing Slicer profiles into PrusaSlicer

## Importing profiles

Importing slicer profiles are quite simple. In the included `.ini` file, profiles for `ABS` and `TPU` have been included. To import these profiles into `PrusaSlicer`, simply click `File > Import > Import Config Bundle` and select the file. This will import the `printer` profiles for `0.4mm` and `0.6mm` nozzle configurations, profiles for `ABS` and `TPU` as well as the default slicer profiles which can be modified by the user

## Starting G-code

For correct operations of the printer, it is required to include specific starting `G-code`, this `G-code` is provided below and can be imported into other slicers. However, this `G-code` uses `variables` from `PrusaSlicer` and might require changes to be made to be used in other slicers:

```gcode
_PRINT_START_PHASE_INIT EXTRUDER={first_layer_temperature[initial_tool]} BED=[first_layer_bed_temperature] MESH_MIN={first_layer_print_min[0]},{first_layer_print_min[1]} MESH_MAX={first_layer_print_max[0]},{first_layer_print_max[1]} LAYERS={total_layer_count} NOZZLE_SIZE={nozzle_diameter[0]}

; Load bed
BED_MESH_PROFILE LOAD="default"
SET_SURFACE_OFFSET OFFSET=0.149

; Insert custom gcode here.
_PRINT_START_PHASE_PREHEAT

; Insert custom gcode here.
_PRINT_START_PHASE_PROBING

; Insert custom gcode here.
_PRINT_START_PHASE_EXTRUDER

; Insert custom gcode here.
_PRINT_START_PHASE_PURGE
```

In this `G-code` the most important part is:

```gcode
_PRINT_START_PHASE_INIT EXTRUDER={first_layer_temperature[initial_tool]} BED=[first_layer_bed_temperature] MESH_MIN={first_layer_print_min[0]},{first_layer_print_min[1]} MESH_MAX={first_layer_print_max[0]},{first_layer_print_max[1]} LAYERS={total_layer_count} NOZZLE_SIZE={nozzle_diameter[0]}
```

This `G-code` initializes the print. It sets the temperature for the `EXTRUDER` and `BED`. Furthermore, it also specifies the `MESH_MIN` and `MESH_MAX`. This allows the slicer to tell the printer what the `min` and `max` dimensions of the print are. This is usefull for `adaptive mesh leveling`, which only levels the print for the area of the print. This greatly reduces leveling time and also allows the user to increase the resolution of the leveling, without requiring to `probe` the entire bed. `LAYERS` tells the printer how many layers there are and is used for `time estimates` and other fun features such as `GCODE AT LAYER` and other more advanced features such as color changes. Finally `NOZZLE_SIZE` tells `Klipper` what the size of the nozzle is and allows `Klipper` to perform more advanced compensation and flow control.

`SET_ENCLOSURE_TEMPERATURE TARGET=50.0` could also be added to set the temperature for the enclosure. Where `50.0` can be changed to any other temperature. The max temperature for the enclosure is however restricted to `60.0` in the firmware to prevent overheating and for safety.

The following section is used to specify the `printing surface` for `Klipper`:

```gcode
; Load bed
BED_MESH_PROFILE LOAD="default"
SET_SURFACE_OFFSET OFFSET=0.149
```

This tells `Klipper` that it should use the printing surface with the name `default` and is useful if the user has many different build plates which have different thicknesses and leveling meshes. It also specifies the `surface z-offset`, which is useful for different filaments requiring different amounts of squish for the first layer.

```gcode
; Insert custom gcode here.
_PRINT_START_PHASE_PREHEAT

; Insert custom gcode here.
_PRINT_START_PHASE_PROBING

; Insert custom gcode here.
_PRINT_START_PHASE_EXTRUDER

; Insert custom gcode here.
_PRINT_START_PHASE_PURGE
```

The last segment is implement using an open-source library called `KlipperMacros`, users can read more about it [here](https://github.com/jschuh/klipper-macros). This is used to level the bed, probe and perform an initial purge, which is automatically calculated based of the aforementioned `MIN` and `MAX` mesh parameters.

Finally, the following end `G-code` should be added in the `END Gcode` section:

```gcode
PRINT_END
SET_ENCLOSURE_TEMPERATURE TARGET=0.0
; total layers count = [total_layer_count]
```

Here `PRINT_END` tells the printer that the end of the print has been reached and `SET_ENCLOSURE_TEMPERATURE TARGET=0.0` tells the printer to ensure that the enclosure heater turns off.

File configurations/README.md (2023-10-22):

# Configuration files

These files are used to configure `Klipper` and most of them are copied to the `printer_data` directory on the `Raspberry Pi`. These configuration files can be used to initialize `Klipper` again to its default and original state.

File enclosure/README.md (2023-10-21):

# Enclosure

This folder contains all files required to flash `ESP Home` to the `ESP32` which controls the enclosure. `enclosure.yaml` is the configuration file for the `ESP32` and `secrets.yaml` is the file used to specify the credentials used for the `WiFi` and `MQTT Broker` settings.

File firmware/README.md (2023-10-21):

# Firmware

This is folder contains the `FIRMWARE.bin` file currently installed on the printer. This file can be written to an `SD card` and be used to flash the printer with `Klipper`. It is however important to note that certain updates to `Klipper` on the `Raspberry Pi` might require a new `FIRMWARE.bin` file to be created for the printer, depending on the changelog.

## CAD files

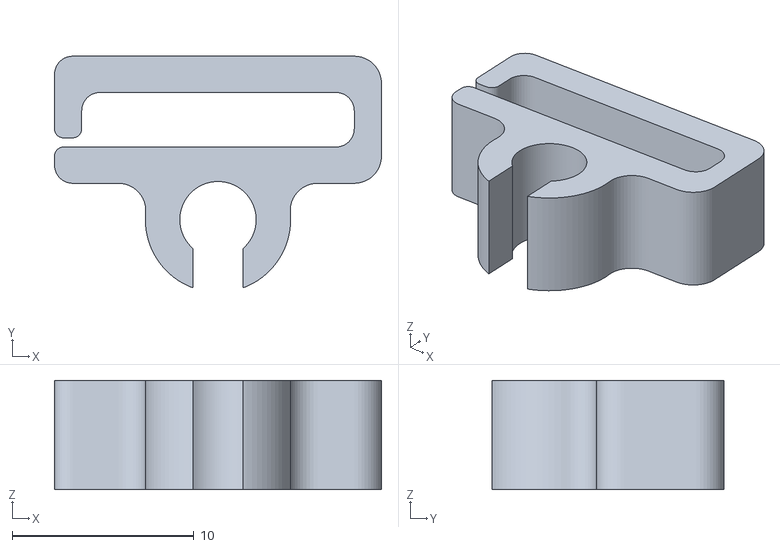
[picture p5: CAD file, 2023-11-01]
models/bowden_clips/BowdenClip_v2.stl
18.0 x 12.8 x 6.00

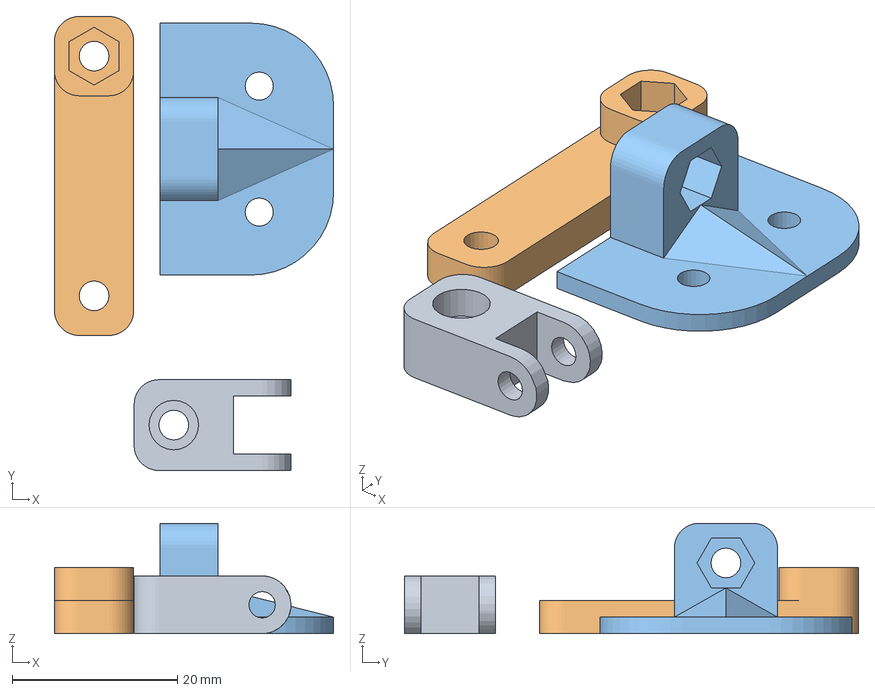
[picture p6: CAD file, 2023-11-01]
models/camera/mount.3mf
33.8 x 55.0 x 13.4 mm
c270_cam_mount.stl_1
c270_cam_mount.stl_2
c270_cam_mount.stl_3

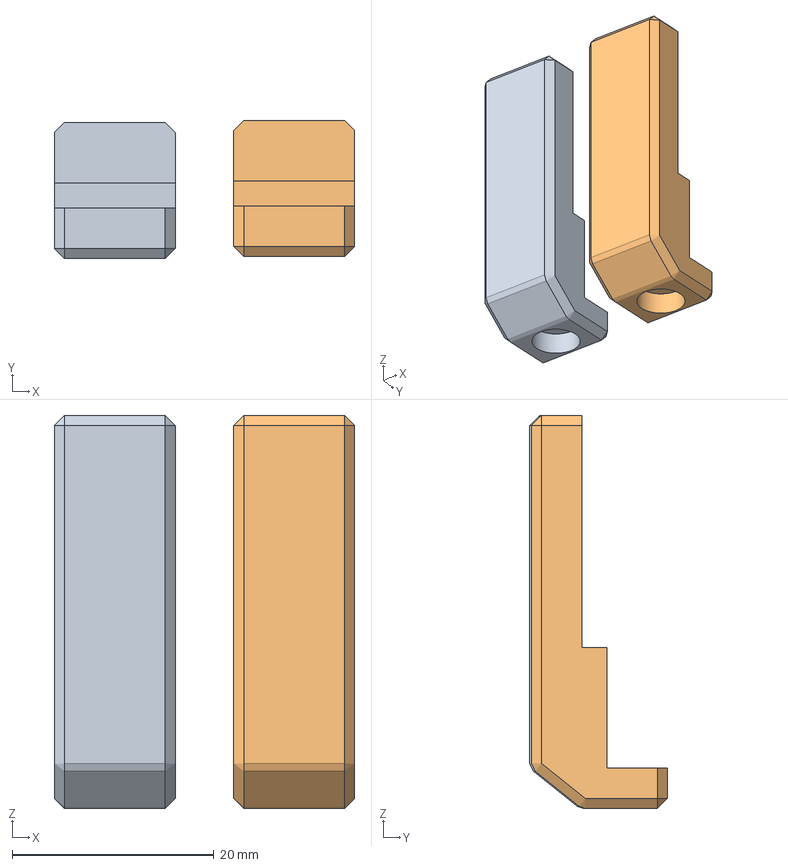
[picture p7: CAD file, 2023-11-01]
models/door_magnet_mounts/MagnetMount.3mf
29.8 x 13.7 x 39.0 mm

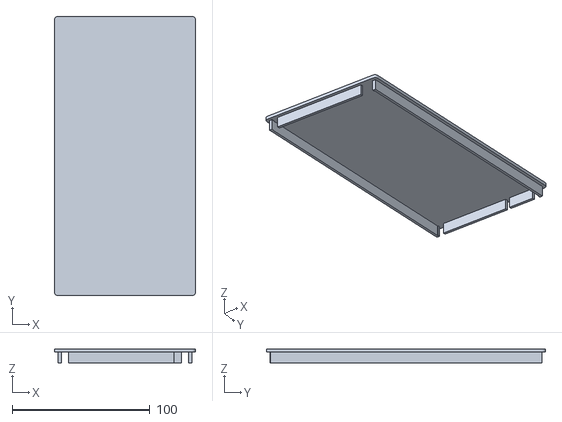
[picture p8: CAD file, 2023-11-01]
models/electronics_enclosure/electronics_enclosure_top.stl
102.5 x 203.0 x 10.5

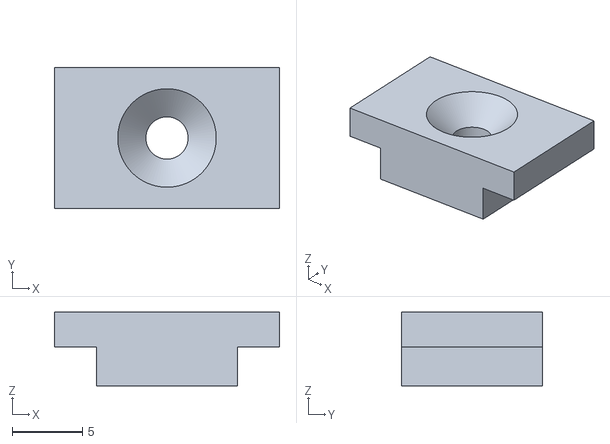
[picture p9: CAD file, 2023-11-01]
models/enclosure_mount/enclosure_mount.stl
16.0 x 10.0 x 5.25

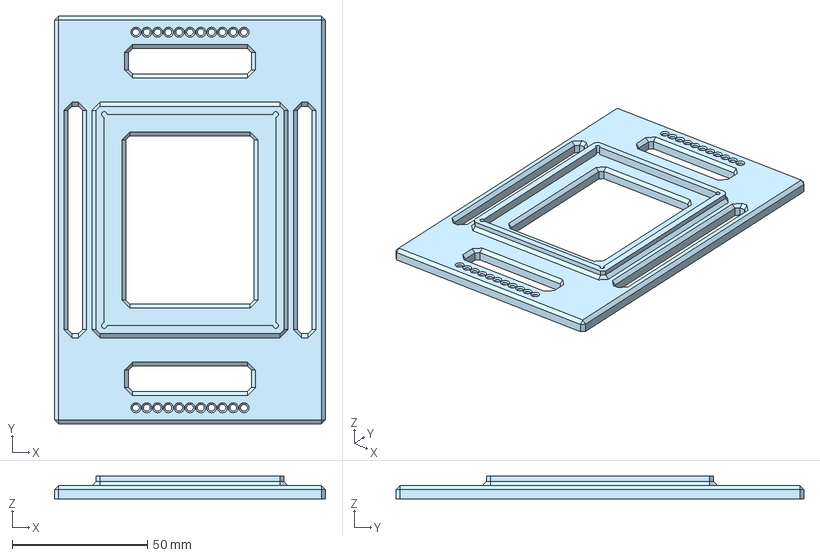
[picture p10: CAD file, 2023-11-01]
models/esp32_mount_plate/ESP_Mount.step
100.3 x 151.0 x 8.50 mm

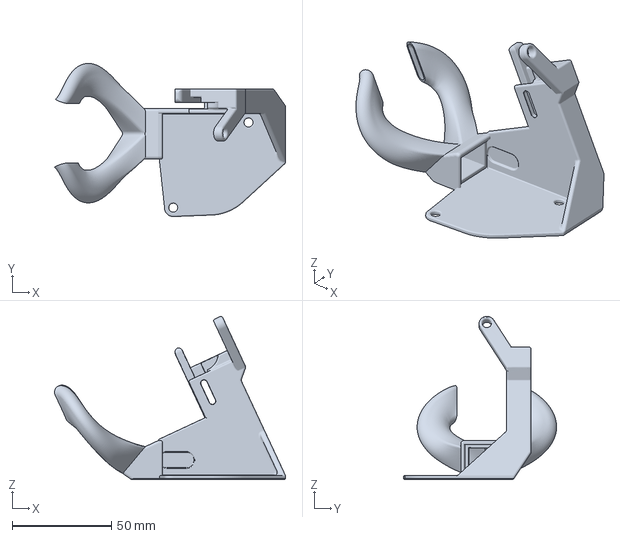
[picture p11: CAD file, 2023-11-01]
models/fan_duct/fan_duct.3mf
116.7 x 77.3 x 82.5 mm

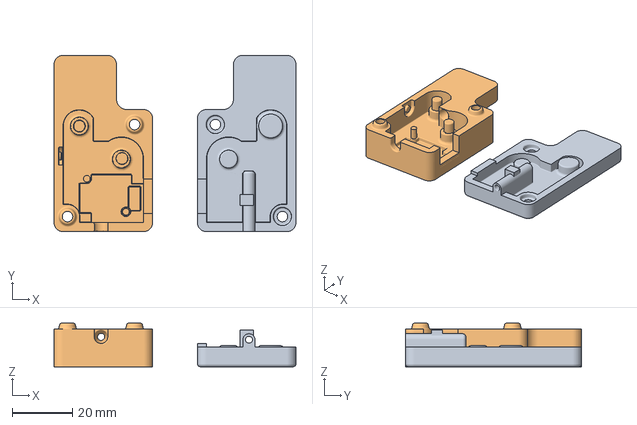
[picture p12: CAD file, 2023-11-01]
models/filament_sensor/filament_sensor.3mf
80.5 x 58.6 x 14.5 mm
ROS_Housing_top_W_spacer.stl
ROS_Housing_bottom_W_spacer.stl

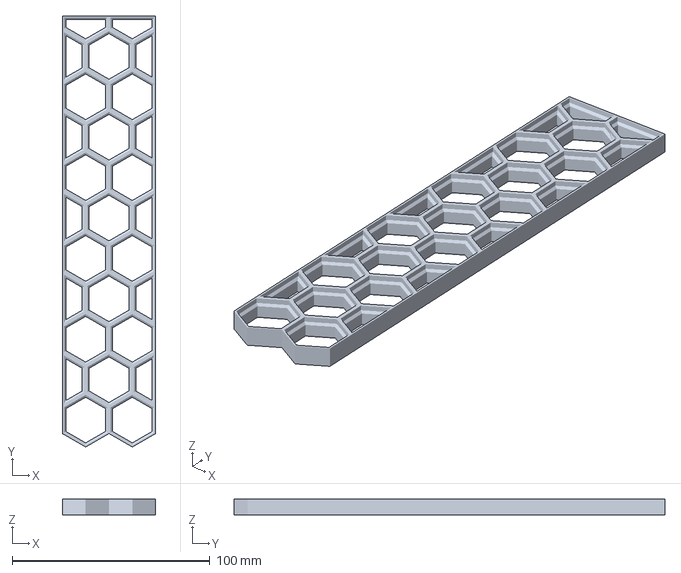
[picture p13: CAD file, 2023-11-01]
models/honeycomb_wall/honeycomb_wall_220x50.3mf
47.2 x 218.0 x 8.00 mm

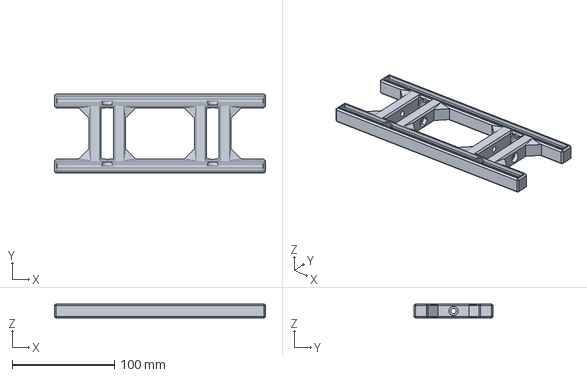
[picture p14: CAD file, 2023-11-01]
models/led_bar/led_bar_v5.step
206.3 x 77.7 x 14.1 mm

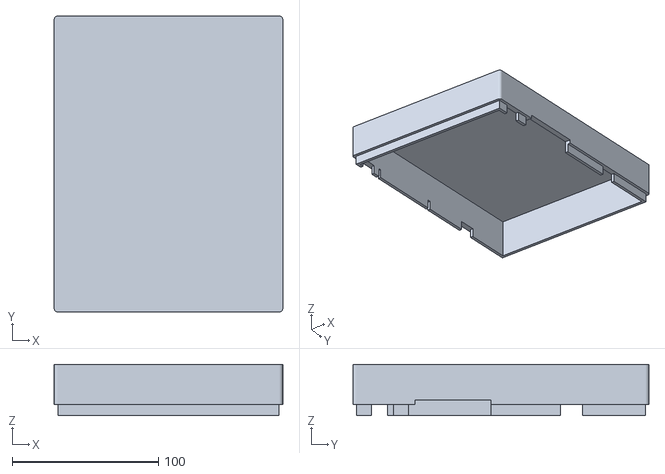
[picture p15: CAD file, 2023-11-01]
models/pi_enclosure/pi_enclosure_top.stl
156.3 x 202.4 x 35.0

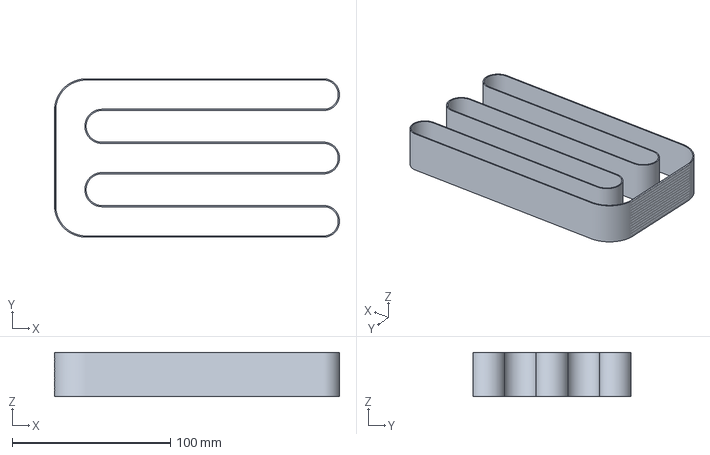
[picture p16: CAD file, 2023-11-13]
volumetric_flow_tests/Max volumetric speed test SpriteExtruder.3mf
180.0 x 100.0 x 28.0 mm

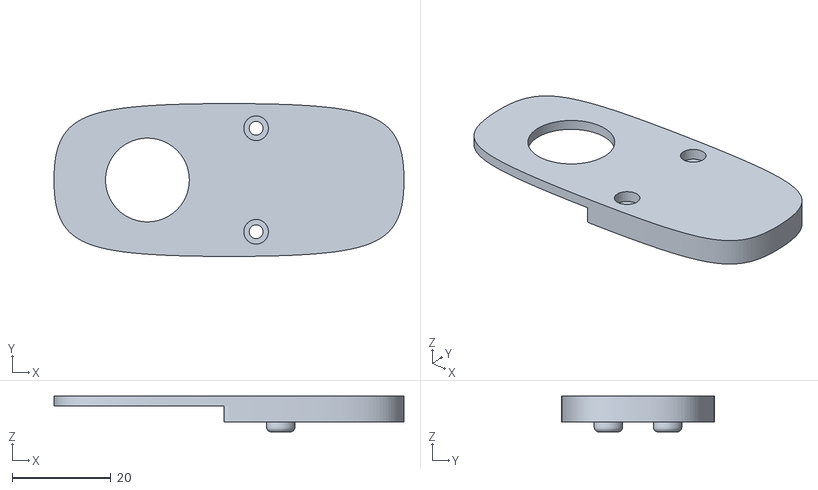
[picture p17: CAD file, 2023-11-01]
models/camera/cover.stl
71.0 x 31.0 x 7.30

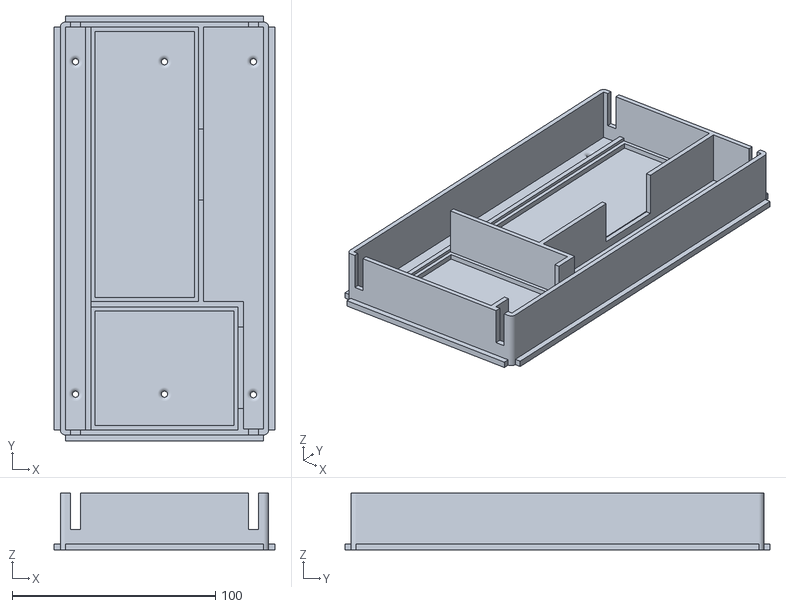
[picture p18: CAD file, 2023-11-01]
models/electronics_enclosure/electronics_enclosure_bottom.stl
108.5 x 209.0 x 28.0

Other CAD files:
models/fan_duct/daughter_board_mount.3mf
models/honeycomb_wall/honeycomb_wall_web_cam_rail.3mf
models/led_bar/parametric_led_bar_v5.step
models/pi_enclosure/pi_enclosure_bottom.stl
models/camera/base.stl
models/camera/focus_ring.stl
models/esp32_mount_plate/ESP_Mount.3mf
models/honeycomb_wall/cover_contersunk.3mf
models/honeycomb_wall/cover_contersunk.stl
models/honeycomb_wall/honeycomb_wall_100x50.3mf
models/honeycomb_wall/honeycomb_wall_120x50.3mf
models/honeycomb_wall/honeycomb_wall_210x50.3mf
models/honeycomb_wall/honeycomb_wall_230x50.3mf
models/honeycomb_wall/honeycomb_wall_230x50_flipped.3mf
models/honeycomb_wall/honeycomb_wall_40x50.3mf
models/honeycomb_wall/honeycomb_wall_60x50.3mf
models/honeycomb_wall/honeycomb_wall_80x50_flipped.3mf
models/honeycomb_wall/hook.3mf
models/honeycomb_wall/hook.step
models/honeycomb_wall/hook.stl
models/honeycomb_wall/hook_10mm.step
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

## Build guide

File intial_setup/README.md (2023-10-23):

# Initial Setup

## Printer construction

For the initial setup and construction of the printer, the setup is quite simple. The original `manual` has been included in the `manual/` folder. In this `manual` the user will see that 4 screws need to be used to mount the gantry to the base of the printer. A top handle is also included, which can be added and the printer will still fit in the enclosure. However, for some reason a different `allen key` is used for this handle, which was never included in the original toolkit.

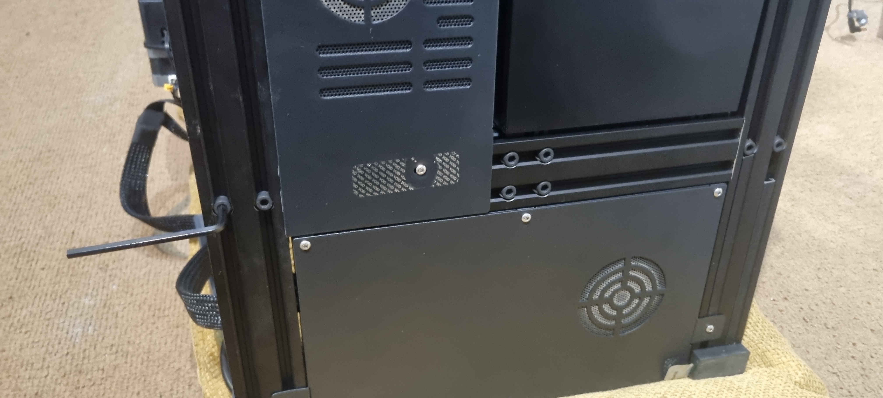
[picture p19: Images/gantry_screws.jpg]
Gantry screws


In the top of the packaging, a drawer is included and the tools have been removed and placed in a zip lock bag in the printer's box. This drawer can be inserted in the front of the printer.

Then, the two motors should be connected, using the `white` connectors on the base of the printer. These connectors will be close to the mounts of the motors and the user will easily see how to connect them.

Then the hotend and motor wire needs to be connected. This is the long cord in the sleave and is connected to the base and motherboard of the printer. This wire needs to be connected to the socket, just below the red filament sensor. The cord should then be connected to the bowden tube and be connected to the daughterboard of the hotend.

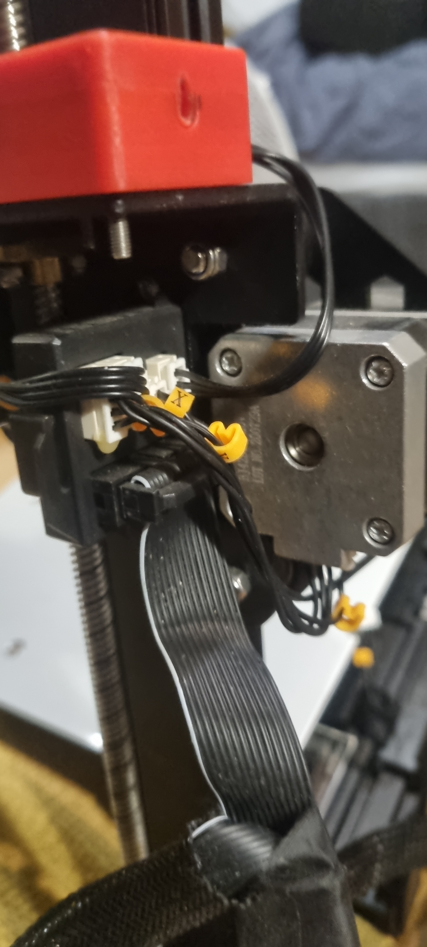
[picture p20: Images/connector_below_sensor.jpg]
Connector below sensor


This cable can also be stabilized using the included printed support arm:

Cable feed arm

Finally, the z-stop sensor needs to be connected. It is positioned on the front left of the printer and has a black connector. These connectors are also close to each other and the user will easily notice them.

## Placing the printer in the enclosure

First start by inserting the two included `light bulbs` in the back left and right-hand corners. Although the bulbs are not identical, there connectors are and order does not matter.

In order to place the printer in the enclosure, the top `LED` bar needs to be disconnected, by removing the two screws. The `LED` bar stays connected with its wire, but can be placed on the top of the enclosure, to keep it out of the way. The printer can then be inserted into the enclosure. 

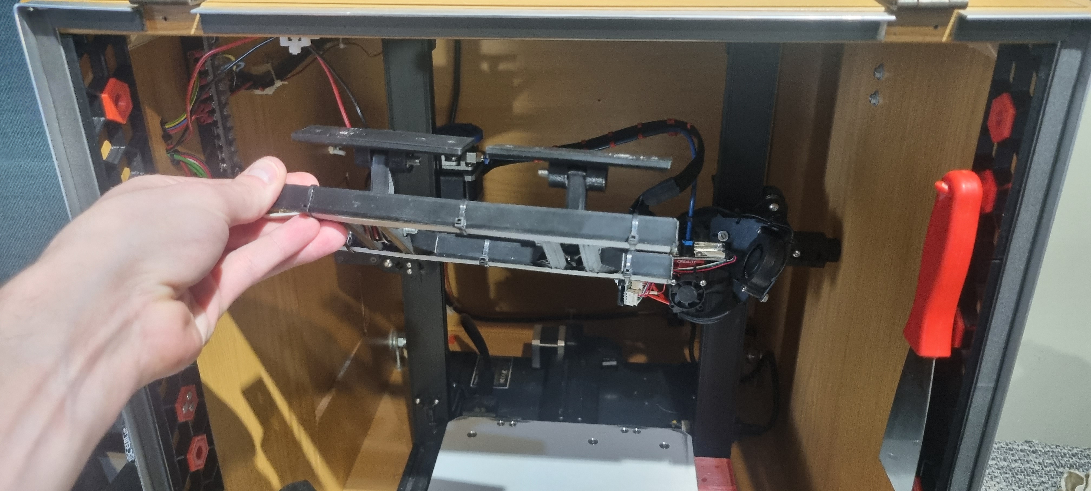
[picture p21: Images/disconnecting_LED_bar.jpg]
Disconnecting LED bar


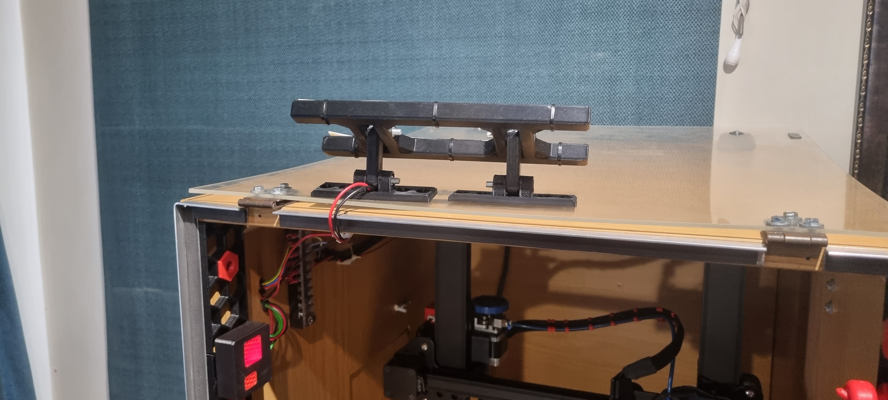
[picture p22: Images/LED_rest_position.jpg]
LED bar rest position


Note, that there are two L-shaped blocks at the back. The printer should be moved to the back, that the feet of the printer are against these blocks.

L-shaped blcoks

The printer can then be connected on the left-hand side to connect its AC power.

Then the black plastic enclosure can be removed on the left-hand side of the enclosure, to reveal the bottom module containing the `Raspberry Pi` and `ESP32`. A `webcam` and `2 USB` cables have been included, as well as a `WiFi dongle`. The user can then plug in `1 USB` cable into the `Raspberry Pi`. Please note there is a small piece of `black isolation tape` on one of the cables. This is to isolate the printer's power from the `Raspberry Pi` to ensure that they do not attempt to power each other. `DO NOT REMOVE THIS TAPE` and plug it in as is.

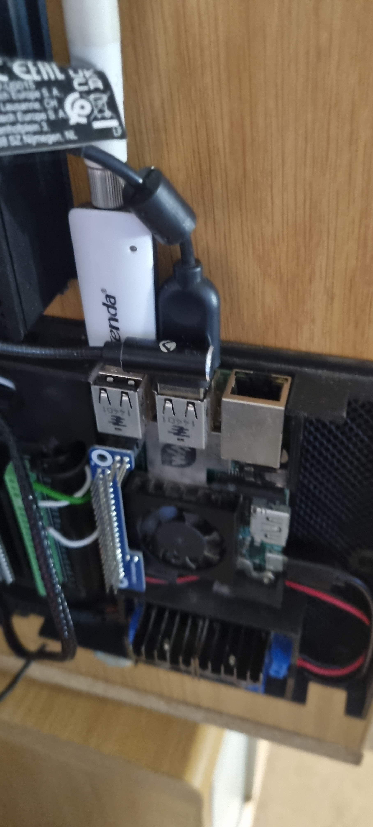
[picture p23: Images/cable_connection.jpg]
Cable connection


At this point, the `ESP32` can also be carefully removed, by holding the plate it is mounted on and pulling it out in a straight line. We will be setting the `WiFi` settings on the `ESP32` in the next section.

The `webcam` can then also be connected, and the cables fed through the side of the enclosure and the printer can be connected on its front left-hand side.

Web cam and printer wiring

The `LED` bar can then be connected to the enclosure again.

Keep the black enclosure on the side open for now as we still need access to the `ESP32`.

## Wifi setup

This guide is intended to isolate the setup for the `WiFi` functionality and the printer. If the both the `ESP32` for the enclosure and `Raspberry Pi` is already setup and pre-installed, this guide needs to be followed to connect the printer to a new network. The process only needs to be completed once to connect to a new network

### Raspberry Pi

In order to connect the `Raspberry Pi` to a new network, an `HDMI` cable needs to be plugged into the `Raspberry Pi` and a `keyboard` needs to be connect. This is required to gain access to the terminal of the `Raspberry Pi`. Once both the `keyboard` and monitor are connected, ensure that a `WiFi dongle` is plugged into one of the `USB` ports of the `Raspberry Pi`, you can power it on by connecting a `micro USB` cable to the power connector. Wait for the `Raspberry Pi` to boot until you are prompted for a `password`.

The default `password` for the `Raspberry Pi` is `root`. While entering the `password` no text will be displayed on the screen. Simply press `enter` after entering the `password` and you will be logged in.

#### Adding your network credentials

Enter the following commands line by line separately in the terminal, pressing `enter` after every line. Be sure to replace `ssid` with your `WiFi network name` and `password` with your `password`. They should be enclosed by the single quotes.

```bash
sudo rfkill unblock wifi
sudo sh -c "wpa_passphrase 'ssid' 'password' >> /etc/wpa_supplicant/wpa_supplicant.conf"
sudo wpa_cli -i wlan0 reconfigure
```

`Reboot` the `Raspberry Pi` by typing `reboot` into the terminal. Wait for the `Raspberry Pi` to reboot and login again.

Once the system is booted, enter the command `ifconfig` and you'll be presented by an output such as the following:

```bash
pi@mainsail:~ $ ifconfig
eth0: flags=4099<UP,BROADCAST,MULTICAST>  mtu 1500
        ether b8:27:eb:3c:98:b5  txqueuelen 1000  (Ethernet)
        RX packets 0  bytes 0 (0.0 B)
        RX errors 0  dropped 0  overruns 0  frame 0
        TX packets 0  bytes 0 (0.0 B)
        TX errors 0  dropped 0 overruns 0  carrier 0  collisions 0

lo: flags=73<UP,LOOPBACK,RUNNING>  mtu 65536
        inet 127.0.0.1  netmask 255.0.0.0
        inet6 ::1  prefixlen 128  scopeid 0x10<host>
        loop  txqueuelen 1000  (Local Loopback)
        RX packets 12  bytes 1698 (1.6 KiB)
        RX errors 0  dropped 0  overruns 0  frame 0
        TX packets 12  bytes 1698 (1.6 KiB)
        TX errors 0  dropped 0 overruns 0  carrier 0  collisions 0

wlan0: flags=4163<UP,BROADCAST,RUNNING,MULTICAST>  mtu 1500
        inet 192.168.1.59  netmask 255.255.255.0  broadcast 192.168.1.255
        inet6 fe80::b087:ae52:2982:2133  prefixlen 64  scopeid 0x20<link>
        ether c8:3a:35:c3:d9:3e  txqueuelen 1000  (Ethernet)
        RX packets 655  bytes 145261 (141.8 KiB)
        RX errors 0  dropped 0  overruns 0  frame 0
        TX packets 344  bytes 156595 (152.9 KiB)
        TX errors 0  dropped 0 overruns 0  carrier 0  collisions 0
```

Note the output for `wlan0`, this is the `Wireless dongle`. The section `inet 192.168.1.59` is the `ip address` of the `Raspberry Pi` on your network. `ether c8:3a:35:c3:d9:3e` is the `MAC` address of the dongle. The `ip address` in your output may differ as this is provided by your network and router. The `MAC` address might be the same depending on the dongle you used. 

### Static IP settings

The `ip address` displayed in the previous section is very important. This is the address of the printer on the network. Although the `ip address` is supplied by your router, it might not remain constant and may change every 48 hours or so, which is not desired. For this reason, we want to supply it with a `static ip address`, this will ensure that the `Raspberry Pi` will always have the same address, which is required for you to easily connect to your printer as well as connect the `ESP32` which controls the enclosure to your printer.

First, we need to find the `ip address` of your `router`. Run the following command to get this:

```bash
ip r | grep default
```

The output should look something like this:

```bash
default via 192.168.1.1 dev wlan0 proto dhcp src 192.168.1.59 metric 303 
```

Note the part `192.168.1.1`, which might differ for you, this is the `ip address` of your router. We will call it `<router ip>` for now, that you can use it in the following sections.

Next, we need to find your `DNS` server. You can find this using the following command. This command will prompt you for your `password` of your `Raspberry Pi` and open the terminal text editor afterwards.

```bash
sudo nano /etc/resolv.conf
```

The output should look something like this:

```bash
# Generated by resolvconf
domain RT-AC58U_V3-3C28
nameserver 192.168.1.1
```

Note the `ip address` after `nameserver`. We will call this `<dns ip>`. Press `ctrl+x` to exit this editor and return to the terminal.

Now we are ready to set the `static ip address`. Start by entering the following command. This will once again open a terminal text-editor.

```bash
sudo nano /etc/dhcpcd.conf
```

The output in your terminal will then possibly be an empty text file or the might be some other configurations. If settings already exist, update the information, other simply enter the following:

- `NETWORK` should be replaced with your interface that you are using, in the case of a `WiFi dongle` you need to enter `wlan0`
- `STATIC_IP/24` should be replaced with your desired `ip address`. For this guide we will use `192.168.1.59/24`. If you choose your own `ip address`, be sure that the third digit marked by an x `192.168.x.y` needs to be the same as the third digit in your `<router ip>` we found earlier and y should always be less than `255` and never numbers like `0`, `1`, `10`, `99` or `100` as they are often used by your network or router, but your could use them if you know what you are doing.
- `ROUTER_IP` should be replaced by your `<router ip>` we found in the previous section.
- `DNS_IP` should be replaced by your `<dns ip>` found in the previous section

```bash
interface NETWORK 
static ip_address=STATIC_IP/24
static routers=ROUTER_IP 
static domain_name_servers=DNS_IP
```

Thus, my implementation looked something like this. Important, if your file contains a lot of other information, do not change any of these settings. Also, if the lines already exist in the file, but they start with a `#`, remove it. The `#` acts as a comment line and these lines are thus commented out and not active, as seen below in my configuration.

```bash
interface wlan0
static ip_address=192.168.1.59/24
static routers=192.168.1.1
static domain_name_servers=192.168.1.1 8.8.8.8 fd51:42f8:caae:d92e::1
```

Once done, press `ctrl+x` and you will be prompted at the bottom of the screen to save the file. Press `shift+y` to select `yes` and press `enter` to confirm to overwrite the file contents. You will then be returned to the terminal screen. Finally, we can `reboot` the system again, by running the command `reboot` in the terminal.

## ESP32 and ESP Home

First start by going to the `root` directory with the following command

```bash
cd ~
```

Then we want to go to the directory of the `ESP32` configuration

```bash
cd OpenEnclosure
```

Then we need to activate the `virtual environment`

```bash
source venv/bin/activate
```

Please not that after activating the `virtual environment` your terminal will change and look like this:

```bash
(venv) pi@mainsail:~/OpenEnclosure $ 
```

The reason for this is we are using `Python virtual environments` which allows for isolated control over dependencies.

```bash
cd enclosure
```

In this folder we have a few files, the two important ones are `enclosure.yaml` and `secrets.yaml`. The `enclosure.yaml` file contains the entire configuration for the `firmware`. This file allows us to program the `firmware` with a simple configuration file. If you look at this file, you will see that it defines different `pins` and `behaviors` for the `ESP32`. Finally, we have the `secrets.yaml` file, which contains our credentials and other parameters. Let's open this file to edit it:

```bash
nano secrets.yaml
```

You should see something like this:

```bash
wifi_ssid: YOUR_WIFI_SSID
wifi_password: YOUR_WIFI_PASSWORD
wifi_ip: 192.168.1.74 # Your static IP for your ESP32
wifi_gateway: 192.168.1.1 # Your default gateway, this is the <router ip> we got in a previous section
wifi_subnet: 255.255.255.0 # Your subnet mask, this is almost always 255.255.255.0

ap_ssid: enclosure 
ap_password: password 

ota_password: password 

mqtt_broker: 192.168.1.59 # This is the IP of your Raspberry Pi
mqtt_username: mainsail # This is your MQTT username
mqtt_password: root # This is your MQTT password
```

Here you need to change a few things:

- You need to change `YOUR_WIFI_SSID` to the name of your `WiFi` network, similar to how we connected the `Raspberry Pi` to your `WiFi`.
- You also need to change and set the `YOUR_WIFI_PASSWORD` to the `password` of your `WiFi` network.
- `wifi_ip` will be the `ip address` that you want for the `ESP32`, similar to how we set the `static ip` of the `Raspberry Pi`, you need to chose an `ip address` for the `ESP32`.
- `wifi_gateway` will be the same as the `<router ip>` we found in the previous section
- `wifi_subnet` is the `subnet mask` of your router. For most users this will always be `255.255.255.0`.

- `ap_ssid` is the name for a `hotspot` the `ESP32` can create. If the `ESP32` is unable to connect to a `WiFi` network, it will create its own `access point` and you will be able to connect to it and set the `ssid` and `password` in your browser.
- `ap_password` will be the `password` of this `hotspot` which the `ESP32` creates.

- `ota_password` is the password which `esp_home` on the `Raspberry Pi` can use to update the `ESP32` over the network, thus eliminating the need for a `USB` cable in the future.

- `mqtt_broker` needs to be the `ip address` of the `Raspberry Pi`. You can find this by using the `ifconfig` command in the terminal of the `Raspberry Pi`, similar to how we did it in previous sections of the guide.
- `mqtt_username` is the username you used for your `MQTT Broker` from the previous section.
- Finally, `mqtt_password` is the `password` for your `MQTT Broker` from the previous section.

Now we are ready to flash the `firmware` to the `ESP32`. First start by opening the bottom panel on the side of the enclosure. The panel should look like this.

Closed enclosure side panel

Open the enclosure by pulling of the top panel, it should look something like this:

Opened enclosure side panel

Ensure that the enclosure is not powered on, this can be notices by the LCD display and lights not be powered on. You can achieve this by disconnecting the main AC plug of the enclosure

Powered off enclosure side panel

Note the orientation of the `ESP32` in the enclosure. Carefully disconnect it by pulling it out of the enclosure. Be sure to hold on to the back panel which the `ESP32` is mounted on, as it can also be removed to reveal the wiring of the `ESP32`:

ESP32 mounting orientation

Connect the `ESP32` with a `USB` cable to the `Raspberry Pi`. Preferably not the `USB` cable used to connect the printer, as it does not provide power to the `ESP32` and the red `LED` on the `ESP32` will not turn on when plugged in. Rather use the extra included `USB` cable.

ESP32 connected to printer

Power on the enclosure, by connecting the AC plug again and wait for the `Raspberry Pi` to boot. After a few minutes you can `SSH` into the `Raspberry Pi` again, or use an externally connected monitor, this is your choice.

Once back in the terminal of the `Raspberry Pi`, let's go back to the directory of the `ESP Home` config, with the following commands

```bash
cd ~
cd OpenEnclosure
```

Now we first need to activate the `Python virtual environment` again with the following command:

```bash
source venv/bin/activate
```

Please not that after activating the `virtual environment` your terminal will change and look like this:

```bash
(venv) pi@mainsail:~/OpenEnclosure $ 
```

Now we can move to the directory of the `.yaml` config file:

```bash
cd enclosure
```

Now we can upload the `firmware` to the `ESP32` with the following command:

```bash
esphome run enclosure.yaml
```

This will run for a while as it is possible that you might not have all the required dependencies the first time you run this command. This can easily take about `10` to `15` minutes the first time you run it.

After this command has run for a while, you will be presented with the following prompt:

```bash
INFO Successfully compiled program.
Found multiple options for uploading, please choose one:
  [1] /dev/ttyUSB0 (CP2102 USB to UART Bridge Controller - CP2102 USB to UART Bridge Controller)
  [2] Over The Air (192.168.1.74)
(number): 
```

This gives us 1 of 2 options. The first option is to flash the `firmware` over the `USB` cable, while second option is for `OTA` or `Over-the-air updates` which allows us to update the `ESP32` over `WiFi`. As the `ESP32` is not yet connected to the `WiFi` network, we will press `1` and then `enter`.

The output should look something like this:

```bash
INFO Successfully compiled program.
Found multiple options for uploading, please choose one:
  [1] /dev/ttyUSB0 (CP2102 USB to UART Bridge Controller - CP2102 USB to UART Bridge Controller)
  [2] Over The Air (192.168.1.74)
(number): 1
esptool.py v4.6.2
Serial port /dev/ttyUSB0
Connecting....
Chip is ESP32-D0WD (revision v1.0)
Features: WiFi, BT, Dual Core, 240MHz, VRef calibration in efuse, Coding Scheme None
Crystal is 40MHz
MAC: 8c:aa:b5:a2:a0:04
Uploading stub...
Running stub...
Stub running...
Changing baud rate to 460800
Changed.
Configuring flash size...
Auto-detected Flash size: 4MB
Flash will be erased from 0x00010000 to 0x0011dfff...
Flash will be erased from 0x00001000 to 0x00005fff...
Flash will be erased from 0x00008000 to 0x00008fff...
Flash will be erased from 0x0000e000 to 0x0000ffff...
Compressed 1103120 bytes to 718365...
Wrote 1103120 bytes (718365 compressed) at 0x00010000 in 17.3 seconds (effective 510.6 kbit/s)...
Hash of data verified.
Compressed 17440 bytes to 12128...
Wrote 17440 bytes (12128 compressed) at 0x00001000 in 0.6 seconds (effective 235.6 kbit/s)...
Hash of data verified.
Compressed 3072 bytes to 144...
Wrote 3072 bytes (144 compressed) at 0x00008000 in 0.1 seconds (effective 330.8 kbit/s)...
Hash of data verified.
Compressed 8192 bytes to 47...
Wrote 8192 bytes (47 compressed) at 0x0000e000 in 0.1 seconds (effective 463.2 kbit/s)...
Hash of data verified.

Leaving...
Hard resetting via RTS pin...
INFO Successfully uploaded program.
INFO Starting log output from /dev/ttyUSB0 with baud rate 115200
```

After this process has been completed, you will start to see `logging` and other information from the `ESP32`, which verifies that flashing the `firmware` was successful and it has successfully connected to the `MQTT Broker` on the `Raspberry Pi`. You might however notice some errors, this will be due to the `ESP32` not being connected to the sensors in the enclosure, so you can ignore them for now:

```bash
INFO Successfully uploaded program.
INFO Starting log output from /dev/ttyUSB0 with baud rate 115200
[11:17:03][I][logger:271]: Log initialized
[11:17:03][C][ota:473]: There have been 0 suspected unsuccessful boot attempts.
[11:17:03][D][esp32.preferences:114]: Saving 1 preferences to flash...
[11:17:03][D][esp32.preferences:143]: Saving 1 preferences to flash: 0 cached, 1 written, 0 failed
[11:17:03][I][app:029]: Running through setup()...
[11:17:03][I][i2c.arduino:183]: Performing I2C bus recovery
[11:17:03][C][switch.gpio:011]: Setting up GPIO Switch 'Printer Power'...
[11:17:03][D][switch:016]: 'Printer Power' Turning OFF.
[11:17:03][D][switch:055]: 'Printer Power': Sending state OFF
[11:17:03][D][switch:016]: 'Printer Power' Turning OFF.
[11:17:03][C][switch.gpio:011]: Setting up GPIO Switch 'LED Lights Power'...
[11:17:03][D][switch:016]: 'LED Lights Power' Turning OFF.
[11:17:03][D][switch:055]: 'LED Lights Power': Sending state OFF
[11:17:03][D][switch:016]: 'LED Lights Power' Turning OFF.
[11:17:03][C][light:035]: Setting up light 'Enclosure Heating Lights'...
[11:17:03][D][light:036]: 'Enclosure Heating Lights' Setting:
[11:17:03][D][light:041]:   Color mode: 
[11:17:03][D][light:085]:   Transition length: 1.0s
[11:17:03][D][main:409]: Booting
[11:17:03][D][light:036]: 'Enclosure Heating Lights' Setting:
[11:17:03][D][light:085]:   Transition length: 1.0s
[11:17:03][D][climate:011]: 'Enclosure Heating Lights Climate' - Setting
[11:17:03][D][climate:015]:   Mode: HEAT
[11:17:03][D][climate:040]:   Target Temperature: 0.00
[11:17:03][D][climate:378]: 'Enclosure Heating Lights Climate' - Sending state:
[11:17:03][D][climate:381]:   Mode: HEAT
[11:17:03][D][climate:383]:   Action: OFF
[11:17:03][D][climate:401]:   Current Temperature: nan°C
[11:17:03][D][climate:407]:   Target Temperature: 0.00°C
[11:17:03][C][sgp4x:012]: Setting up SGP4x...
[11:17:03][E][sensirion_i2c:085]: Failed to write i2c register=0x3682 (2) err=2,
[11:17:03][E][sgp4x:017]: Failed to read serial number
[11:17:03][E][component:113]: Component sgp4x.sensor was marked as failed.
[11:17:03][C][dht:011]: Setting up DHT...
[11:17:03][D][sensor:094]: 'Enclosure Heating Lights PID Proportional': Sending state 0.00000 % with 1 decimals of accuracy
[11:17:03][D][sensor:094]: 'Enclosure Heating Lights PID Integral': Sending state 0.00000 % with 1 decimals of accuracy
[11:17:03][D][sensor:094]: 'Enclosure Heating Lights PID Derivative': Sending state 0.00000 % with 1 decimals of accuracy
[11:17:03][C][wifi:038]: Setting up WiFi...
[11:17:03][C][wifi:051]: Starting WiFi...
[11:17:03][C][wifi:052]:   Local MAC: 8C:AA:B5:A2:A0:04
[11:17:03][D][wifi:428]: Starting scan...
[11:17:03][W][dht:169]: Requesting data from DHT failed!
[11:17:03][W][dht:060]: Invalid readings! Please check your wiring (pull-up resistor, pin number).
[11:17:03][D][esp32.preferences:114]: Saving 3 preferences to flash...
[11:17:03][D][esp32.preferences:143]: Saving 3 preferences to flash: 3 cached, 0 written, 0 failed
[11:17:03][D][sensor:094]: 'Enclosure Heating Lights PID Error': Sending state 0.00000 % with 1 decimals of accuracy
[11:17:03][D][sensor:094]: 'Enclosure Temperature': Sending state nan °C with 1 decimals of accuracy
[11:17:03][D][sensor:094]: 'Enclosure Heating Lights PID Proportional': Sending state 0.00000 % with 1 decimals of accuracy
[11:17:03][D][sensor:094]: 'Enclosure Heating Lights PID Integral': Sending state 0.00000 % with 1 decimals of accuracy
[11:17:03][D][sensor:094]: 'Enclosure Heating Lights PID Derivative': Sending state 0.00000 % with 1 decimals of accuracy
[11:17:03][D][climate:378]: 'Enclosure Heating Lights Climate' - Sending state:
[11:17:03][D][climate:381]:   Mode: HEAT
[11:17:03][D][climate:383]:   Action: IDLE
[11:17:03][D][climate:401]:   Current Temperature: nan°C
[11:17:03][D][climate:407]:   Target Temperature: 0.00°C
```

Once you received this output. You can power off the `Raspberry Pi` and unplug the `AC` plug of the enclosure and install the `ESP32` back into the enclosure. Please note the orientation is EXTREMELY important and that the pins are correctly aligned. They should fit perfectly as there is the correct amount of pins.

ESP32 mounting orientation

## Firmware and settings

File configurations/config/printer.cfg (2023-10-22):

########################################################
#        Mainsail Config
########################################################
[display_status]
[exclude_object]
[include mainsail.cfg]

########################################################
#        Klipper-Macros
########################################################
[include klipper_macros.cfg]

########################################################
#        Custom Macros
########################################################
[include macros.cfg]

########################################################
#        Input-Shaper
########################################################
# [include input_shaper.cfg]

########################################################
#        Gcode Arcs
########################################################
[gcode_arcs]
resolution: 0.1

########################################################
#         MCU
########################################################
[mcu]
serial: /dev/serial/by-id/usb-1a86_USB_Serial-if00-port0
restart_method: command

########################################################
#      Printer
########################################################
[printer]
kinematics: cartesian
max_velocity: 100
max_accel: 500
max_accel_to_decel: 1000
max_z_velocity: 12
max_z_accel: 250
square_corner_velocity: 5.0

########################################################
#        MCU PI
########################################################
[mcu rpi]
serial: /tmp/klipper_host_mcu

########################################################
#        Steppers
########################################################
[stepper_x]
step_pin: PB8
dir_pin: !PB7
enable_pin: !PC3
rotation_distance: 40
microsteps: 16
endstop_pin: PC4
position_min: -5
position_endstop: -5
position_max: 235
homing_speed: 80

[stepper_y]
step_pin: PB6
dir_pin: PB5
enable_pin: !PC3
rotation_distance: 40
microsteps: 16
endstop_pin: PC5
position_min: -5
position_endstop: -5
position_max: 235
homing_speed: 80

[stepper_z]
step_pin: PB4
dir_pin: !PB3
enable_pin: !PC3
rotation_distance: 8
microsteps: 16
endstop_pin: probe:z_virtual_endstop
position_min: -1.5
position_max: 255
homing_speed: 4
second_homing_speed: 1
homing_retract_dist: 2.0

########################################################
#         Extruders
########################################################
[extruder]
max_extrude_only_distance: 1000.0
step_pin: PC2
dir_pin: !PB9
enable_pin: !PC3
rotation_distance: 31.33015
microsteps: 16
nozzle_diameter: 0.4
filament_diameter: 1.750
heater_pin: PA1
sensor_type: EPCOS 100K B57560G104F
sensor_pin: PB1
#control: pid
pressure_advance: 0.45
#pid_kp = 22.692
#pid_ki = 1.104
#pid_kd = 116.580
min_temp: 0
max_temp: 265

########################################################
#       Heaters
########################################################
[heater_bed]
heater_pin: PA2
sensor_type: EPCOS 100K B57560G104F
sensor_pin: PB0
control: pid
pid_kp = 67.350
pid_ki = 1.754
pid_kd = 646.562
min_temp: 0
max_temp: 120

########################################################
#       Fans
########################################################
[fan]
pin: PA0
kick_start_time:1.0

[heater_fan my_nozzle_fan]
pin: PD2
max_power: 1.0
shutdown_speed : 0
heater:extruder
heater_temp : 60
fan_speed : 1.0

########################################################
#       Probe
########################################################
[probe]
pin: PA4
#   Probe detection pin. If the pin is on a different microcontroller
#   than the Z steppers then it enables "multi-mcu homing". This
#   parameter must be provided.
deactivate_on_each_sample: True
#   This determines if Klipper should execute deactivation gcode
#   between each probe attempt when performing a multiple probe
#   sequence. The default is True.
x_offset: 0.0
#   The distance (in mm) between the probe and the nozzle along the
#   x-axis. The default is 0.
y_offset: 0.0
#   The distance (in mm) between the probe and the nozzle along the
#   y-axis. The default is 0.
#z_offset: 0.0
#   The distance (in mm) between the bed and the nozzle when the probe
#   triggers. This parameter must be provided.
speed: 3.0
#   Speed (in mm/s) of the Z axis when probing. The default is 5mm/s.
samples: 3
#   The number of times to probe each point. The probed z-values will
#   be averaged. The default is to probe 1 time.
sample_retract_dist: 1.0
#   The distance (in mm) to lift the toolhead between each sample (if
#   sampling more than once). The default is 2mm.
lift_speed: 3.0
#   Speed (in mm/s) of the Z axis when lifting the probe between
#   samples. The default is to use the same value as the 'speed'
#   parameter.
samples_result: average
#   The calculation method when sampling more than once - either
#   "median" or "average". The default is average.
samples_tolerance: 0.100
#   The maximum Z distance (in mm) that a sample may differ from other
#   samples. If this tolerance is exceeded then either an error is
#   reported or the attempt is restarted (see
#   samples_tolerance_retries). The default is 0.100mm.
samples_tolerance_retries: 3
#   The number of times to retry if a sample is found that exceeds
#   samples_tolerance. On a retry, all current samples are discarded
#   and the probe attempt is restarted. If a valid set of samples are
#   not obtained in the given number of retries then an error is
#   reported. The default is zero which causes an error to be reported
#   on the first sample that exceeds samples_tolerance.
#activate_gcode:
#   A list of G-Code commands to execute prior to each probe attempt.
#   See docs/Command_Templates.md for G-Code format. This may be
#   useful if the probe needs to be activated in some way. Do not
#   issue any commands here that move the toolhead (eg, G1). The
#   default is to not run any special G-Code commands on activation.
#deactivate_gcode:
#   A list of G-Code commands to execute after each probe attempt
#   completes. See docs/Command_Templates.md for G-Code format. Do not
#   issue any commands here that move the toolhead. The default is to
#   not run any special G-Code commands on deactivation.
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

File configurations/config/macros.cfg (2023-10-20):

########################################################
#         MACROS: Messages
########################################################
[gcode_macro _INFO]
description: Display an info message
  usage: _INFO [MESSAGE="<message>"]
gcode:
    {% set message = params.MESSAGE|default("INFO") %}
    {action_respond_info(message)}

[gcode_macro _ERROR]
description: Display an error message
    usage: _ERROR [MESSAGE="<message>"]
gcode:
    {% set message = params.MESSAGE|default("ERROR") %}
    {action_raise_error(message)}

[gcode_macro _EMERGENCY_STOP]
description: Display an emergency stop message and shutdown the printer
  usage: _EMERGENCY_STOP [MESSAGE="<message>"]
gcode:
    ENCLOSURE_LIGHTS_OFF
    SET_ENCLOSURE_HEATERS_OFF
    {% set message = params.MESSAGE|default("EMERGENCY STOP") %}
    {action_emergency_stop(message)}

########################################################
#         MACROS: Motors off
########################################################
[gcode_macro MOTORS_OFF]
description: Turn motors off
gcode:
    M84 X Y E  

########################################################
#         MACROS: MQTT
########################################################
[gcode_macro MQTT_PUBLISH]
description: Publish value to MQTT topic
gcode:
    {% set value = params.VALUE %}
    {% set topic = params.TOPIC %}
    {% set qos = params.QOS | default(0) %}
    {% set retain = params.RETAIN | default(True) %}

    {% set message = 'TOPIC=[%s] VALUE=[%s]' | format(topic|string, value|string) %}
    {% set cmd = '_INFO MESSAGE="%s"'| format(message) %}
    { cmd }

    {% set _payload = {"value": value} %}

    {action_call_remote_method("publish_mqtt_topic",
                               topic=topic,
                               payload=_payload,
                               qos=qos,
                               retain=retain,
                               use_prefix=True)}

########################################################
#         MACRO: Enclosure Temperature
########################################################
[gcode_macro SET_ENCLOSURE_TEMPERATURE]
description: Gcode to set enclosure temperature
gcode:
  {% set target = params.TARGET|default(50)|float %}
  {% set topic = "klipper/state/temperature_sensor enclosure_temperature/target" %}

  {% if target <= 0 %}
      {% set target = 0 %}
      _INFO MESSAGE="ENCLOSURE_HEATERS_OFF"
  {% else %}
      _INFO MESSAGE="ENCLOSURE_HEATERS_ON"
      _INFO MESSAGE={"ENCLOSURE_TEMPERATURE_TARGET=%f" | format(target) }
  {% endif %}

  {% set _payload = {"value": target} %}
  
  {action_call_remote_method("publish_mqtt_topic",
                             topic=topic,
                             payload=_payload,
                             qos=0,
                             retain=True,
                             use_prefix=True)}

[gcode_macro SET_ENCLOSURE_HEATERS_OFF]
description: Gcode to turn enclosure heaters off
gcode:
  SET_ENCLOSURE_TEMPERATURE TARGET=0

########################################################
#         MACRO: Start print
########################################################
[gcode_macro PRINT_START]
rename_existing: KM_PRINT_START
gcode:

  # Put macro code here to run before PRINT_START.

  # Turn lights on
  ENCLOSURE_LIGHTS_ON
  KM_PRINT_START {rawparams}
  # Put macro code here to run after PRINT_START but before the print gcode

########################################################
#         MACRO: End Print
########################################################
[gcode_macro PRINT_END]
rename_existing: KM_PRINT_END
gcode:

  # Put macro code here to run before PRINT_END.

  KM_PRINT_END {rawparams}

  # Put macro code here to run after PRINT_END but before the print gcode
  SET_ENCLOSURE_HEATERS_OFF

########################################################
#         MACRO: Color change
########################################################
[gcode_macro COLOR_CHANGE]
description: Trigger color change
gcode:
    # Activace color change
    M600

########################################################
#         MACRO: Before layer change
########################################################
[gcode_macro BEFORE_LAYER_CHANGE]
rename_existing: KM_BEFORE_LAYER_CHANGE
gcode:
  {% set layer = params.LAYER|default(-1)|int + 1 %}
  {% set topic = "klipper/state/layer" %}
  {% set _payload = {"value": layer} %}
  
  {action_call_remote_method("publish_mqtt_topic",
                             topic=topic,
                             payload=_payload,
                             qos=0,
                             retain=True,
                             use_prefix=True)}

  KM_BEFORE_LAYER_CHANGE {rawparams}

[gcode_macro AFTER_LAYER_CHANGE]
rename_existing: KM_AFTER_LAYER_CHANGE
gcode:
  KM_AFTER_LAYER_CHANGE {rawparams}


########################################################
#         MACRO: Printer nozzle LED 
########################################################
[gcode_macro LED_ON]
description: Turn printer LED ON
gcode:
    SET_PIN PIN=led VALUE=1

[gcode_macro LED_OFF]
description: Turn printer LED OFF
gcode:
    SET_PIN PIN=led VALUE=0

########################################################
#        MACRO: Enclosure Lights
########################################################
[gcode_macro ENCLOSURE_LIGHTS_ON]
gcode:
    {action_call_remote_method("set_device_power",
                             device="enclosure_lights",
                             state="on",
                             force=True)}
    
[gcode_macro ENCLOSURE_LIGHTS_OFF]
gcode:
    {action_call_remote_method("set_device_power",
                             device="enclosure_lights",
                             state="off",
                             force=True)}

[gcode_macro ENCLOSURE_LIGHTS_TOGGLE]
gcode:
    {action_call_remote_method("set_device_power",
                             device="enclosure_lights",
                             state="toggle",
                             force=True)}

########################################################
#        MACRO: Printer Power
########################################################
[gcode_macro PRINTER_OFF]
gcode:
    SET_ENCLOSURE_HEATERS_OFF
    ENCLOSURE_LIGHTS_OFF
    {action_call_remote_method("set_device_power",
                             device="printer",
                             state="off",
                             force=True)}
  

[gcode_macro PRINTER_ON]
gcode:
    ENCLOSURE_LIGHTS_ON
    {action_call_remote_method("set_device_power",
                             device="printer",
                             state="on",
                             force=True)}

[gcode_macro SHUTDOWN]
gcode:
  _INFO MESSAGE="Shutting down"
  ENCLOSURE_LIGHTS_OFF
  SET_ENCLOSURE_HEATERS_OFF
  {action_call_remote_method("shutdown_machine")}

[gcode_macro REBOOT]
gcode:
  _INFO MESSAGE="Rebooting"
  {action_call_remote_method("reboot_machine")}

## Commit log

2023-09-17 added auto tune button
2023-09-18 autotuned PID
2023-09-18 renamed variables, improved logging, pid tune
2023-09-19 pid tuning, removed debug mqtt outputs
2023-09-21 added relay controls
2023-09-24 Added air quality testing and relay control
2023-10-15 added enclosures for sensors
    [Sensor_Enclosure.3mf, Sensors_Enclosure.step]
2023-10-15 corrected restore_mode syntax error
    [enclosure.yaml]
2023-10-20 first guide version
    [input_shaper.cfg, klipper_macros.cfg, macros.cfg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]
2023-10-21 turned off power_save_mode
2023-10-21 Added enclosure README
2023-10-22 updated configuration files
    [mainsail.cfg, printer-20230919_090632.cfg, printer-20230930_084048.cfg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]
2023-10-22 changed fan and extrusion parameters
2023-10-23 correct USB cable for ESP32
2023-10-23 Added END gcode and enclosure temperature
2023-10-23 Added links to help user with guides
    [Sensor_Enclosure.3mf, Sensors_Enclosure.step]
2023-11-01 added 3d models
    [BowdenClip_v2.stl, ESP_Mount.3mf, ESP_Mount.step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]
2023-11-13 added volumetric flow tests
    [Max volumetric speed test CR6SE.3mf, Max volumetric speed test Ender3V2.3mf]
2023-11-13 sprite extruder
    [Max volumetric speed test SpriteExtruder.3mf]
